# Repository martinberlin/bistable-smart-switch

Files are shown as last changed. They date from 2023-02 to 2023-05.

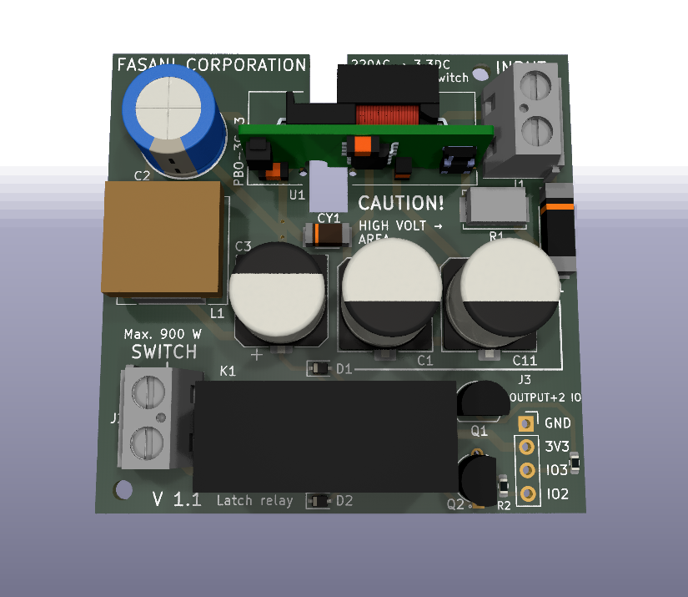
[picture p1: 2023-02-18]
Hardware/220AC-mini-C3-board/3D/img/3d-top.png

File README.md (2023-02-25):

**IMPORTANT:** This repository contains components added as github submodules. Please clone it using

    git clone --recurse-submodules https://github.com/martinberlin/bistable-smart-switch.git
        or if you already cloned it without them just run additionally:
    git submodule update --init --recursive

# Bistable-smart-switch

This is a project that started with the idea to use small, and inexpensive, SPI epapers with touch. The ones that I've found available and met that criteria are produced by Good-Display in Dalian.
The idea is very simple: 

> Use this bistable displays, or any others with very low consumption, to design a Switch that can replace a standard European one.

I know is a lot of technology to turn on the light and at some point I though that no-one will buy a digital switch for a spaceship.

**But it turns out that it got some attention since there are some interesting points that drive this:**

- **ESP32-C3** is also an unexpensive, single Core, RISC-V Espressif MCU with 4 MB flash and the usual BLE/ WiFi combination
- **Having touch and UX with a bistable display**, using our own component CalEPD and our own touch fork, gives us the freedom to be Code-light and make versatile examples that everyone can extend and collaborate
- **ESP-Rainmaker** is a possibility that we already tested, so you can also turn ON/OFF the light with their application
- **There are no similar smart switches** that come with full schematics, PCB's and example Firmware. If there are please tell us where since I'm interested to see what others are doing (We know already jung.de the zamel.com polish brand and more) But none of them offers a hackeable switch.

All that we have already but it was around different repositories, where you had to configure CMakeFiles to point it to the right example and more...
The goal of this repo is to put all this Switch ideas and code demos in a single place, make a WiKi with configuration tutorials and documentation. Just make it easy for the user to get started and build his first working Firmware in 10 minutes.

With the current hardware and demo examples what you can do is straight-forward. You can design a switch, since we provide a very basic example, and detect touch X & Y events. Based on that you can send signals to the Latch relay PCB and move the switch to the ON or OFF position.
But is your switch. You could draw something using GFX over. Soon we will add examples to load images from WiFi and other cool things. And Latch relay is low consumption, you just move it with a 50 ms signal, then it stays in that position.
It has no way to tell in what position is from outside but we know it since by default the ESP32 C3 moves it to OFF as the Firmware starts.

## The hardware

It consists in two PCBs and the display using C3 as Microcontroller:

1. **ESP32-C3 controller with touch**
2. **220AC to 3.3DC adapter with a Latch relay switch**. 54x54 mm so it fits in the small black box inside the wall Can be also a solid-state relay or you can design your own
3. **The 2.7" display** with touch [GDEY027T91-T](https://github.com/martinberlin/cale-idf/wiki/Good-Display-gdey027T91)

C3 controller

3D-mains-power

2.7 touch FocalTech

This is the touch panel that comes already on top of the display. Check the [GOODISPLAY product page](https://www.good-display.com/product/2.7-inch-touch-screen,-for-2.7-inch-e-paper-display-259.html) for specifications and datasheet.

More pictures and documentation will be added in the WiKi section, that is better to keep things organized and inter-linked than a single readme page.

## IO configuration

We will keep mostly the same "proven to work" IOs along the PCB versions but it might be that routing is simpler using different pins for SPI. To keep it organized the default sdkconfig will point to PCB latest release (In this case 1.1) and we will keep track of the right IO config for different versions in the [sdk-config-board](sdk-config-board) directory.

As an example if you have a 1.0 PCB, you can simply cp that sdkconfig to your project one doing this from the project root folder:

    $ cp sdk-config-board/1.0/sdkconfig .

Alternatively you can configure this the usual way with ESP-IDF using menuconfig:

    idf.py menuconfig

    SPI configuration is located in: **Component config → SPI epaper configuration**

    I2C and RTC configuration: **Root → RTC & I2C Configuration**

    WiFi connection for RTC sync: **Root → Example Connection Configuration**

## The code examples

1. [Getting started](main/switch/getting-started) a simple ON-OFF basic switch. No configuration required.

More will soon land here. For the moment they are in mother repository cale-idf that is an incredible mess where I develop the components and is full of examples, that I promised myself to reorganize, and I will probably never do.
Just be patient, life takes it's times, just like the hardware design part and examples.

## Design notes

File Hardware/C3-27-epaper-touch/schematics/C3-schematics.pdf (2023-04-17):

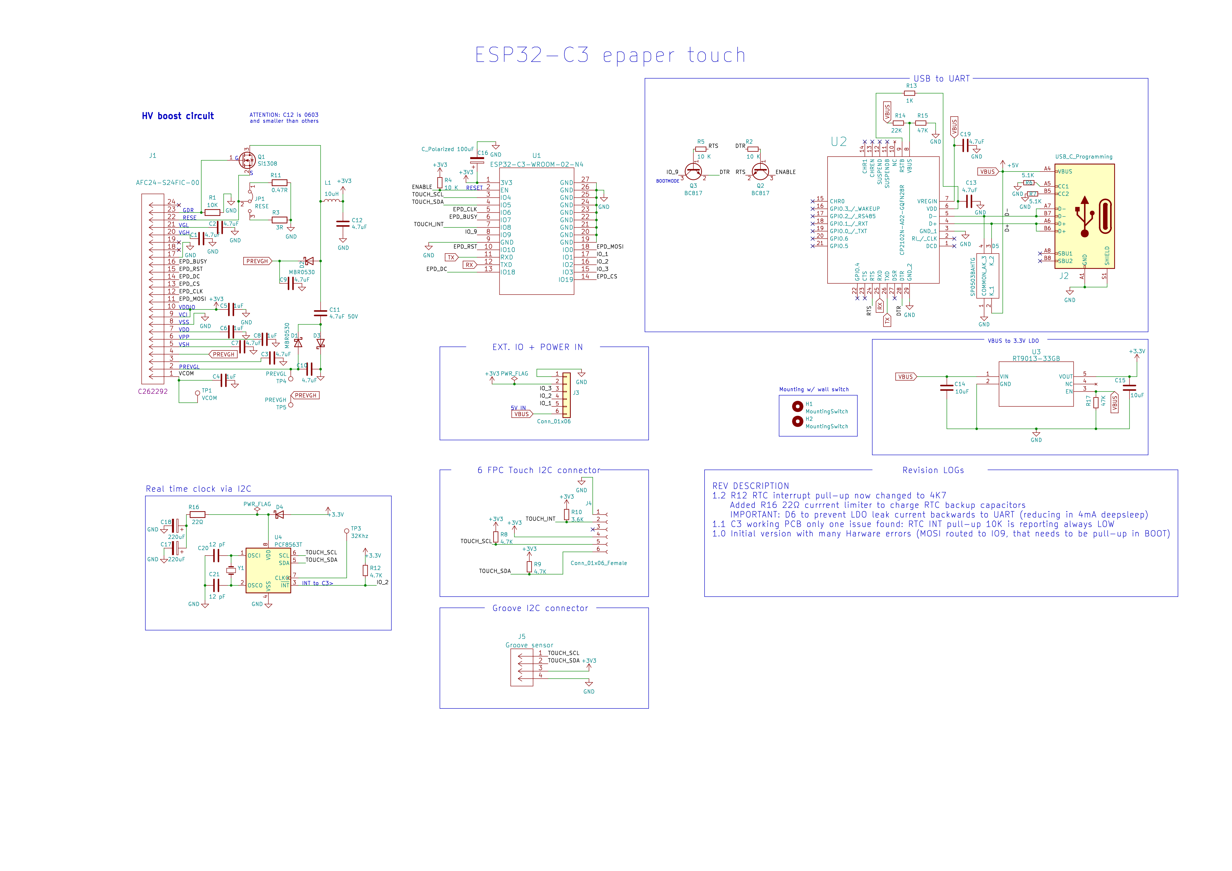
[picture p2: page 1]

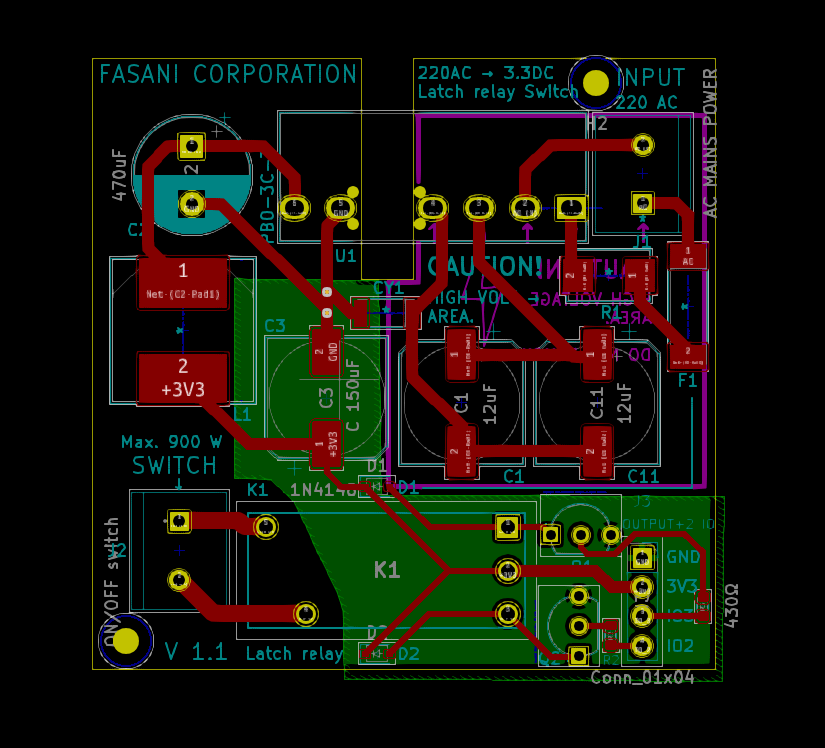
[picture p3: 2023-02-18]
Hardware/220AC-mini-C3-board/3D/img/PCB-top-view.png

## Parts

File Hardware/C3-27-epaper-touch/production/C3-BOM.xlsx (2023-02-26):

Designator | Footprint | Comment | JLPCB Part#
D4 | D_SOD-323 | 1N5819WS | C191023
C2,C7,C9,C10,C19,C1,C3 | C_0805_2012Metric_Pad1.18x1.45mm_HandSolder | 4.7uF | C1779
Q2,Q3 | SOT-23 | BC817 | C146798
C8,C4,C6,C5 | C_0805_2012Metric_Pad1.18x1.45mm_HandSolder | 1uF | C28323
J2 | USB_C_Receptacle_HRO_TYPE-C-31-M-12 | USB_C_Programming | C165948
U3 | SOT-23 | MCP1700-3302E_SOT23 | C39051
R13 | R_0603_1608Metric | 1K | C21190
C11 | C_0805_2012Metric_Pad1.18x1.45mm_HandSolder | 4.7uF 50V | C1779
R11 | R_0603_1608Metric | 0.47R | C103895
C17,C18 | CP_EIA-3528-21_Kemet-B | 220uF | C122252
R3 | R_0603_1608Metric | 3R | C25237
D5 | SP0503BAHTG | SP0503BAHTG | C3040626
U4 | SOIC-8_3.9x4.9mm_P1.27mm | PCF8563T | C7440
Y1 | Q13FC1350000400-Crystal | Crystal_Small | C32346
R2,R5,R12,R4 | R_0603_1608Metric | 10 K | C25804
C21,C20 | C_0603_1608Metric | 12 pF | C38523
JP1 | switch-MK-12C02-G020 | RESE | C2911519
C14,C15 | C_0805_2012Metric | 10uF | C15850
J1 | AFC24-S24FIC-00 | AFC24-S24FIC-00 | C262292
R7,R6 | R_0603_1608Metric | 5.1K | C23186
D1,D3,D2 | D_SOD-123 | MBR0530 | C77336
C13 | C_0805_2012Metric | 4.7uF | C1779
R10 | R_0603_1608Metric | 3.6K | C22980
C16 | CP_EIA-3528-21_Kemet-B | C_Polarized 100uF | C129289
R1 | R_0603_1608Metric | 10K | C25804
J4 | FH34SRJ-6S-0.5SH50-Hirose | Conn_01x06_Female | C224194
R9,R8 | R_0603_1608Metric | 4.7K | C23162
U2 | CP2102-QFN50P500X500X80-29N-D | CP2102N-A02-GQFN28R | C964632
R15 | R_0603_1608Metric | 47.5K | C137715
Q1 | SOT-323_SC-70 | Si1308 | C469327
C12 | C_0603_1608Metric | 4.7uF | C19666
L1 | SWPA4030S1R0NT | 10uH | C38117
R14 | R_0603_1608Metric | 22K | C31850
U1 | ESP32-C3 |  | C2934560

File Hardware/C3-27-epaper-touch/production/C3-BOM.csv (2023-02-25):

Id | Designator | Package | Quantity | Designation | Supplier and ref
1 | D4 | D_SOD-323 | 1 | 1N5819WS
2 | C2,C7,C9,C10,C19,C1,C3 | C_0805_2012Metric_Pad1.18x1.45mm_HandSolder | 7 | 4.7uF
3 | TP3 | TestPoint_Pad_D1.5mm | 1 | 32Khz
4 | U1 | ESP32-C3-WROOM-02-N4 | 1 | ESP32-C3-WROOM-02-N4
5 | Q2,Q3 | SOT-23 | 2 | BC817
6 | C8,C4,C6,C5 | C_0805_2012Metric_Pad1.18x1.45mm_HandSolder | 4 | 1uF
7 | J2 | USB_C_Receptacle_HRO_TYPE-C-31-M-12 | 1 | USB_C_Programming
8 | U3 | SOT-23 | 1 | MCP1700-3302E_SOT23
9 | R13 | R_0603_1608Metric | 1 | 1K
10 | C11 | C_0805_2012Metric_Pad1.18x1.45mm_HandSolder | 1 | 4.7uF 50V
11 | R11 | R_0603_1608Metric | 1 | 0.47R
12 | C17,C18 | CP_EIA-3528-21_Kemet-B | 2 | 220uF
13 | R3 | R_0603_1608Metric | 1 | 3R
14 | D5 | SP0503BAHTG | 1 | SP0503BAHTG
15 | U4 | SOIC-8_3.9x4.9mm_P1.27mm | 1 | PCF8563T
16 | Y1 | Q13FC1350000400-Crystal | 1 | Crystal_Small
17 | R2,R5,R12,R4 | R_0603_1608Metric | 4 | 10 K
18 | C21,C20 | C_0603_1608Metric | 2 | 12 pF
19 | JP1 | switch-MK-12C02-G020 | 1 | RESE
20 | C14,C15 | C_0805_2012Metric | 2 | 10uF
21 | J1 | AFC24-S24FIC-00 | 1 | AFC24-S24FIC-00
22 | R7,R6 | R_0603_1608Metric | 2 | 5.1K
23 | D1,D3,D2 | D_SOD-123 | 3 | MBR0530
24 | C13 | C_0805_2012Metric | 1 | 100nF
25 | R10 | R_0603_1608Metric | 1 | 3.6K
26 | C16 | CP_EIA-3528-21_Kemet-B | 1 | C_Polarized 100uF
27 | R1 | R_0603_1608Metric | 1 | 10K
28 | J4 | FH34SRJ-6S-0.5SH50-Hirose | 1 | Conn_01x06_Female
29 | R9,R8 | R_0603_1608Metric | 2 | 4.7K
30 | U2 | CP2102-QFN50P500X500X80-29N-D | 1 | CP2102N-A02-GQFN28R
31 | R15 | R_0402_1005Metric | 1 | 47K
32 | J5 | MOLEX-I2C-532530470 | 1 | Groove sensor
33 | Q1 | SOT-323_SC-70 | 1 | Si1308
34 | C12 | C_0603_1608Metric | 1 | 4.7uF
35 | L1 | SWPA4030S1R0NT | 1 | 10uH
36 | R14 | R_0201_0603Metric | 1 | 22K

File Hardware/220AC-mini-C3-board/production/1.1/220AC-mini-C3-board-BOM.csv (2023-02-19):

Id | Designator | Package | Quantity | Designation | Supplier and ref
1 | R1 | SMW212RJT | 1 | R
2 | Q1,Q2 | BC547B | 2 | Q_NPN_CBE
3 | R2,R3 | R_0603_1608Metric | 2 | 430Ω
4 | K1 | FH44L-1AT-L2-DC3V | 1 | HF163-F
5 | C11 | CP_Elec_10x14.3 | 1 | 12uF
6 | D2,D1 | D_SOD-323 | 2 | 1N4148
7 | CY1 | CC1808KKX7RCBB102 | 1 | 1nF
8 | U1 | PBO-3C-3 | 1 | PBO-3C-3
9 | J2 | Conn_C8269 | 1 | ON/OFF switch
10 | J1 | Conn_C8269 | 1 | AC MAINS POWER
11 | C2 | CP_Radial_D10.0mm_P5.00mm | 1 | 470uF
12 | F1 | 0443001.DR | 1 | Fuse
13 | L1 | IND_BRL3225T4R7M | 1 | L
14 | C3 | CP_Elec_10x10 | 1 | C 150uF
15 | J3 | PinSocket_1x04_P2.54mm_Vertical | 1 | Conn_01x04

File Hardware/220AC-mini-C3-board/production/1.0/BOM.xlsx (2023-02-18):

Designator | Footprint | Comment | JLPCB Part#
J1 | 1729128-screw-terminal | AC MAINS POWER | C474894
R1 | SMW212RJT | R | C2073396
C1,C11 | CP_Elec_10x14.3 | 12uF | C487569
K1 | HF163FL24HL2T | HF163-F | C140724
D2,D1 | D_SOD-323 | 1N4148 | C2128
CY1 | CC1808KKX7RCBB102 | 1nF | C527384
U1 | PBO-3C-3 | PBO-3C-3 | C5346210
Q1,Q2 | BC547B | Q_NPN_CBE | C713613
C2 | CP_Radial_D10.0mm_P5.00mm | 470uF | C106488
F1 | 0443001.DR | Fuse | C95352
J2 | 1729128-screw-terminal | ON/OFF switch | C474894
C3 | CP_Elec_10x10 | C 150uF | C72490
L1 | SMDRI127-470MT | L | C24548

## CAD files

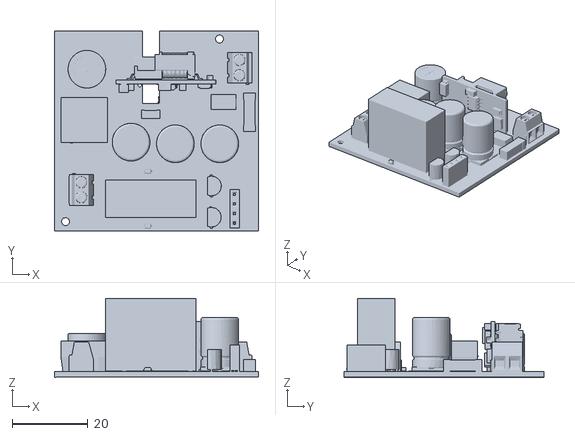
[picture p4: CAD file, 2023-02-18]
Hardware/220AC-mini-C3-board/3D/220ac-mini-c3-board.stl
54.0 x 53.0 x 20.9

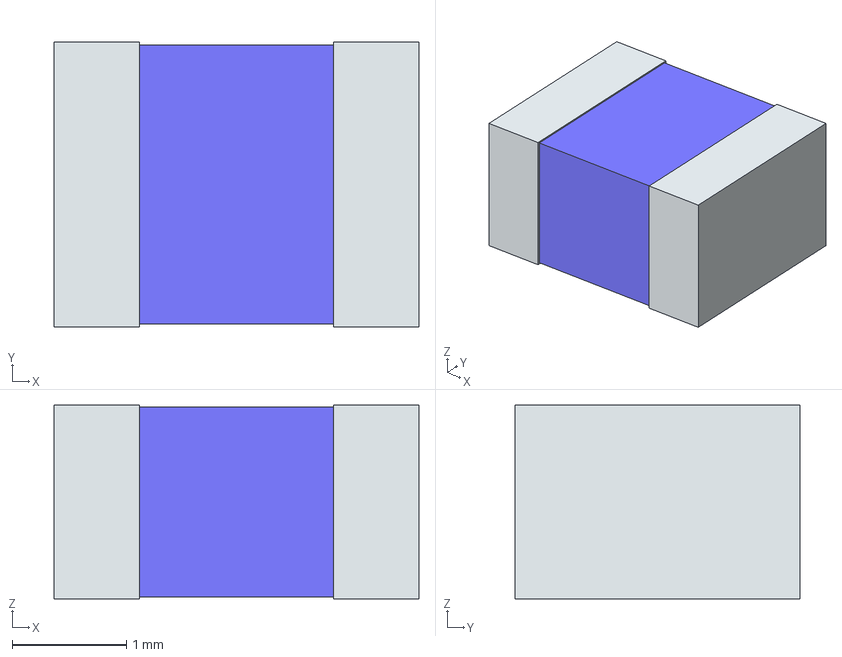
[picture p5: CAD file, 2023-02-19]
Hardware/220AC-mini-C3-board/parts/3d/BRL3225T4R7M-L1.step
3.20 x 2.50 x 1.70 mm
term1
term2

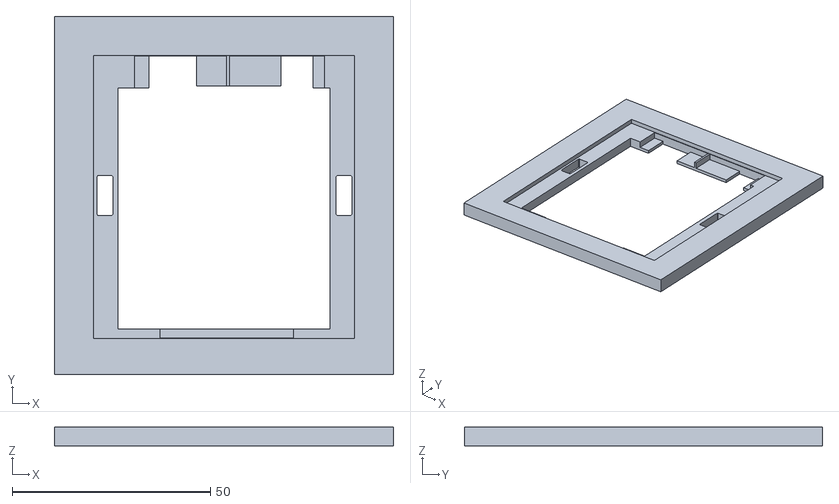
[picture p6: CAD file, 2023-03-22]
Hardware/3D/case-switch-epaper.stl
85.5 x 90.2 x 4.73

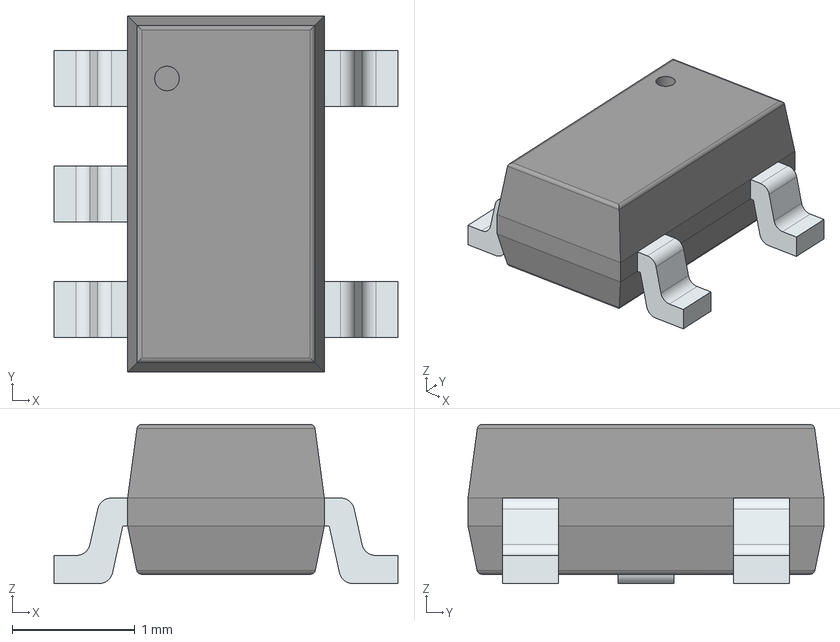
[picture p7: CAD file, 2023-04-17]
Hardware/C3-27-epaper-touch/parts/3d/RT9013-33GB.step
2.79 x 2.90 x 1.29 mm
PinsArrayL
PinsArrayR

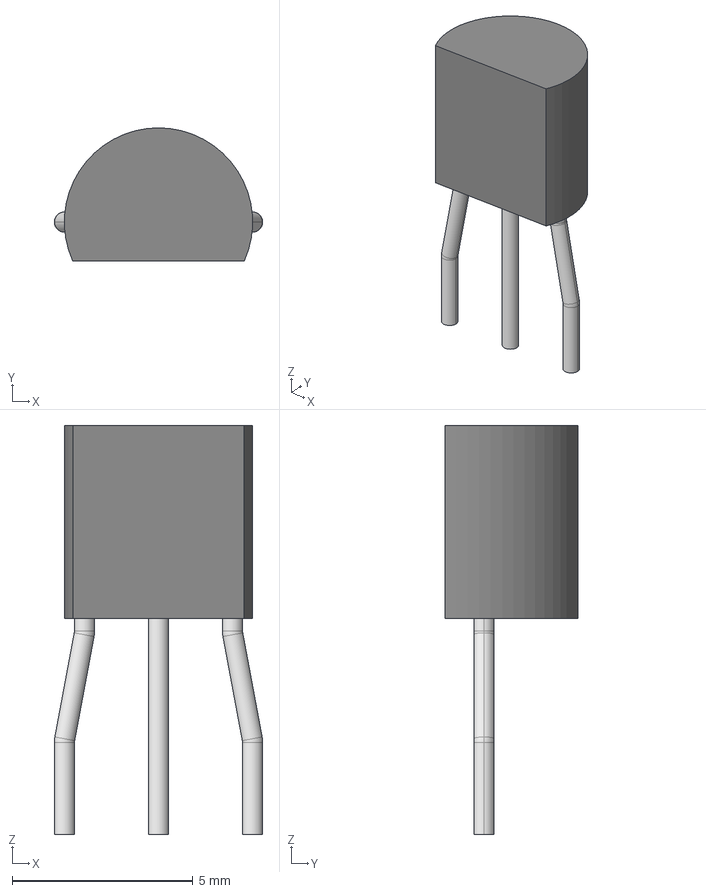
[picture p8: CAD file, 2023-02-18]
Hardware/220AC-mini-C3-board/parts/3d/TO-92-3L_5P33X5P2_ONS.step
5.76 x 3.68 x 11.3 mm

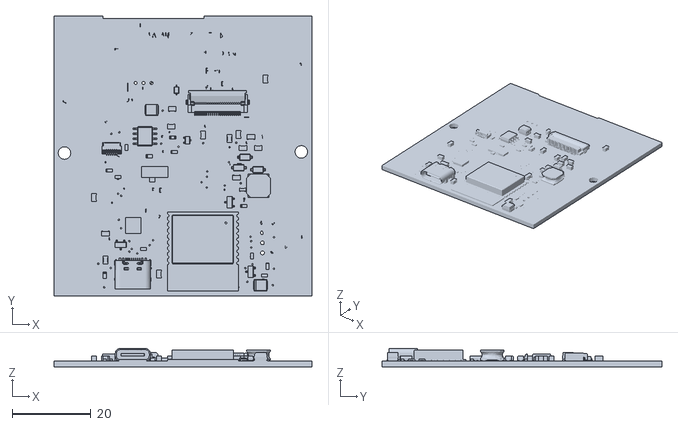
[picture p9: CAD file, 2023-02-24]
Hardware/C3-27-epaper-touch/3D/C3-27-epaper-touch-3D.stl
65.4 x 71.0 x 4.84

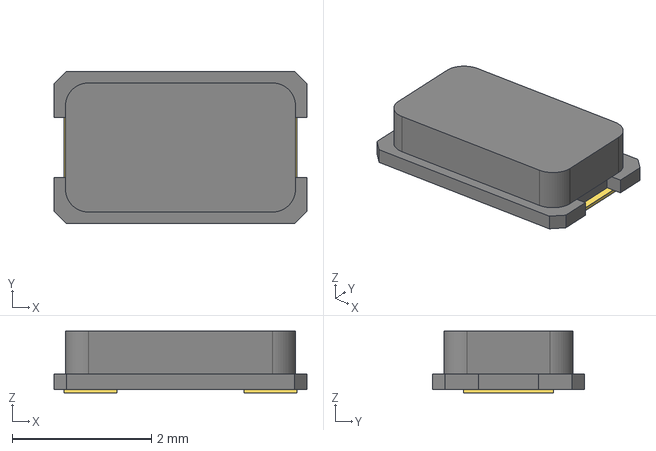
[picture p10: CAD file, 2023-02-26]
Hardware/C3-27-epaper-touch/parts/3d/XTAL_FC-135_EPS.step
3.63 x 2.18 x 0.889 mm

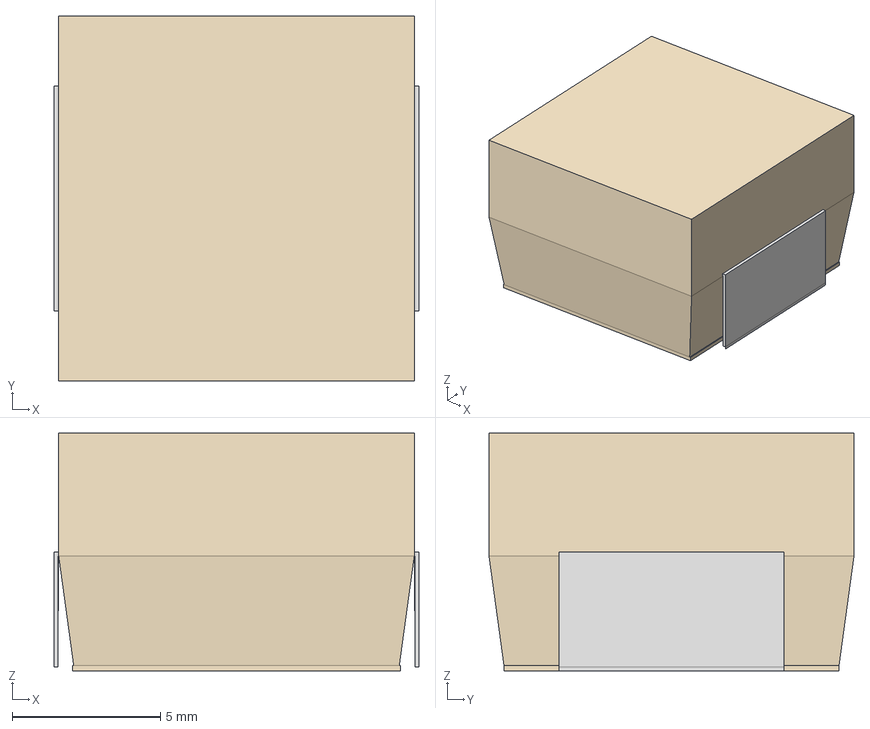
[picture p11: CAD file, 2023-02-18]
Hardware/220AC-mini-C3-board/parts/3d/IND_SMDRI_SXN.step
12.3 x 12.3 x 8.00 mm

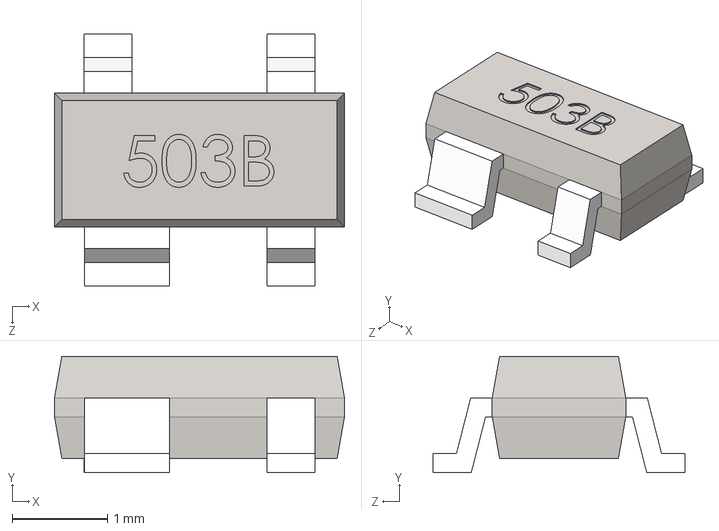
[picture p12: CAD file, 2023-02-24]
Hardware/C3-27-epaper-touch/parts/3d/SP0503BAHTG-ESD.step
3.04 x 1.22 x 2.64 mm

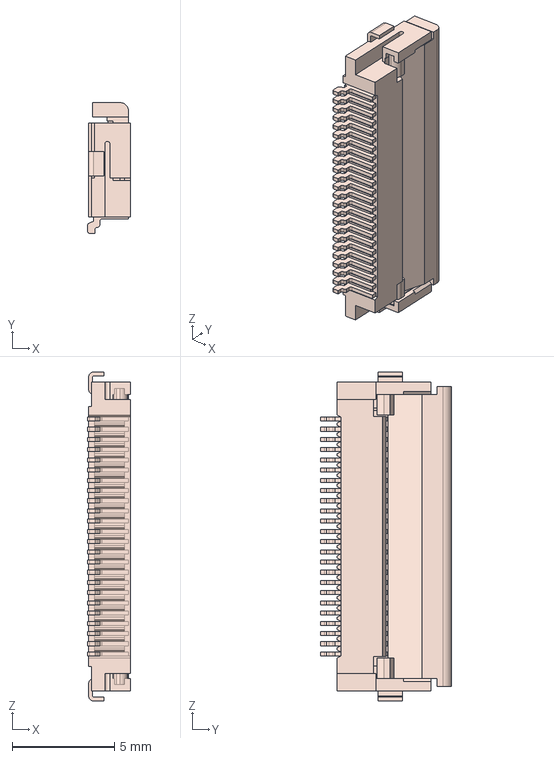
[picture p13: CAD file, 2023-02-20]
Hardware/C3-27-epaper-touch/parts/3d/FH12-24S-0.5SH_55_.step
2.10 x 6.40 x 16.1 mm

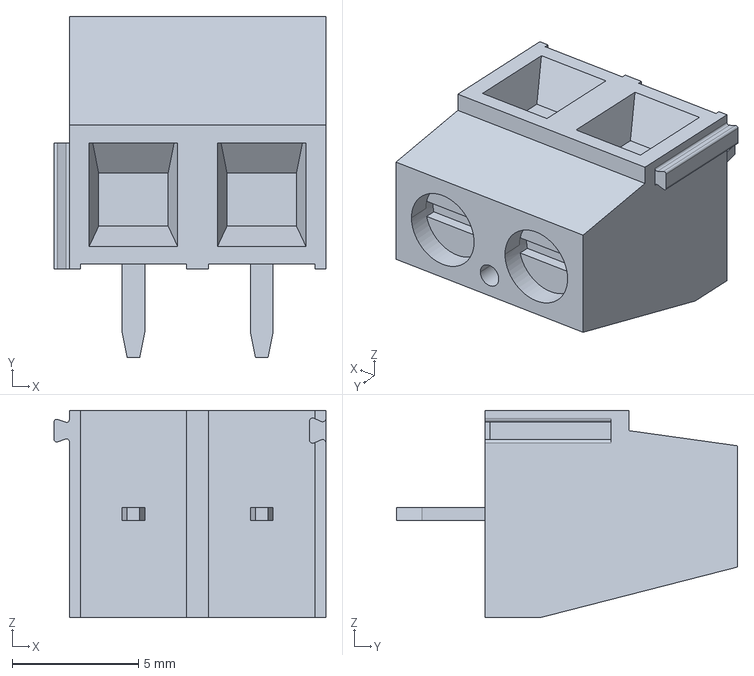
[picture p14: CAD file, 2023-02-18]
Hardware/220AC-mini-C3-board/parts/3d/C8269.step
10.8 x 13.5 x 8.20 mm

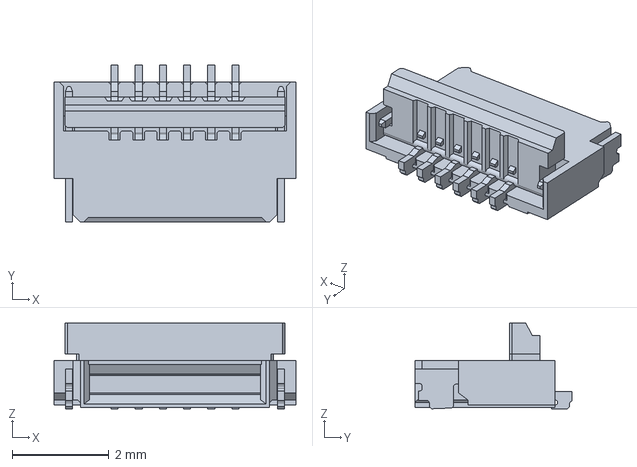
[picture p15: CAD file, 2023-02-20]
Hardware/C3-27-epaper-touch/parts/3d/FH34SRJ-6S-0.5SH50-Hirose.step
5.00 x 3.25 x 1.77 mm

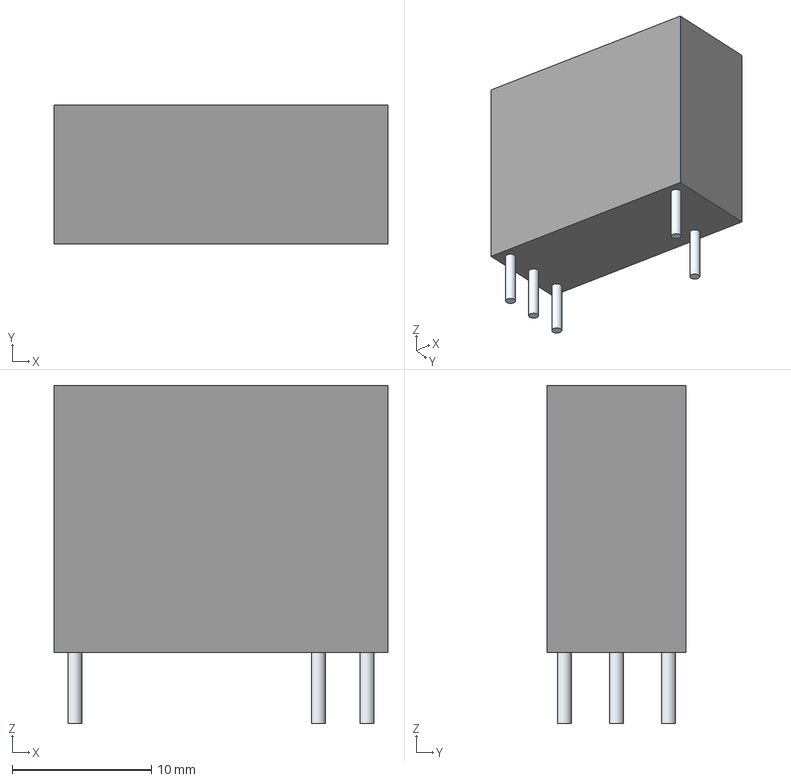
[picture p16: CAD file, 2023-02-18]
Hardware/220AC-mini-C3-board/parts/3d/HF163F-L_24-HL2T.step
24.0 x 10.0 x 24.3 mm
Leads

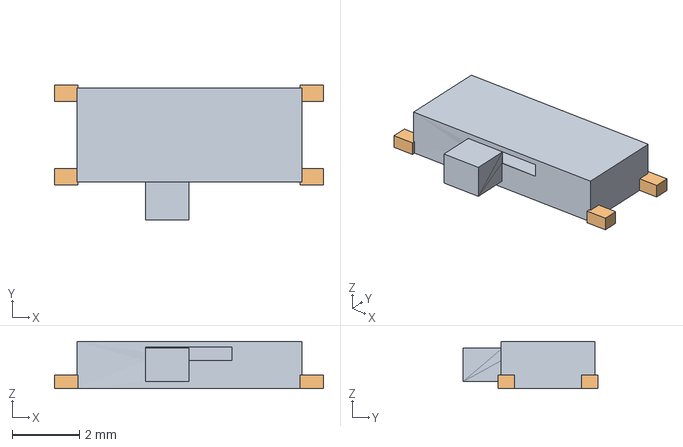
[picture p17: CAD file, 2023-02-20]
Hardware/C3-27-epaper-touch/parts/3d/MK-12C02-G015.step
8.01 x 4.03 x 1.40 mm

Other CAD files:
Hardware/C3-27-epaper-touch/3D/case-switch-epaper.stl
Hardware/S3-27-epaper-touch-pro/3D/case-switch-epaper.stl
Hardware/C3-27-epaper-touch/parts/3d/CR1220-2.step
Hardware/220AC-mini-C3-board/parts/3d/1729128-screw-terminal.stp
Hardware/3D/case-switch-epaper.blend
Hardware/C3-27-epaper-touch/parts/3d/0443Series_LTF.step
Hardware/C3-27-epaper-touch/parts/3d/AP22802AW5-7.step
Hardware/C3-27-epaper-touch/parts/3d/CP2102N-A02-GQFN28R.step
Hardware/C3-27-epaper-touch/parts/3d/ESP32-C3-WROOM-02-H4.step
Hardware/C3-27-epaper-touch/parts/3d/HRO_TYPE-C-31-M-12.step
Hardware/C3-27-epaper-touch/parts/3d/IND_0S282MT_SNL.step
Hardware/C3-27-epaper-touch/parts/3d/L-40xx.STEP
Hardware/C3-27-epaper-touch/parts/3d/c-5-1676966-1-ba-3d.stp

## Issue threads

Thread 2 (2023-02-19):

Kickstart TODOs

martinberlin, 2023-02-19:
- [x] Add ESP-Rainmaker example(s)
- [x] Start WiKi documenting those examples and making a getting started section
- [x] Move [C3-controller](https://github.com/martinberlin/H-spi-adapters) with touch PCB to this repo Hardware section

Update about this point: We will move C3 PCB when the new revision is tested. For now we copied the C3 PCB here but making a PRO version with a more powerful MCU:
ESP32-S3-WROOM-1-N8R2  (with 2MB RAM and 8MB flash) albeit more expensive at 3.9 USD this will be a more powerful option for those who want to research adding more complex Firmware or using LVGL to draw UX.

The WiKi will start soon when we have the first users of the repository.

Closed 2023-02-27.

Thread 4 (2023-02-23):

Hardware PCB improvements

martinberlin, 2023-02-23:
Let’s make a list of things that can be made better:

- [ ] Move C3 design here once it’s validated
- [ ] Add ESD protection diodes to USB
- [ ] Research abou how to add optocoupler to check that light is really consuming in main power PCB

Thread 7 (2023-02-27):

Rainmaker integration

martinberlin, 2023-02-27:
Add this device to be paired to the ESP-Rainmaker phone app

- [ ] Add 2 input forms: Device watts, Price per kilowatt
- [ ] Save the updated values in NVS

But this is not only meant to be WiFi driven for the people that do not want that. Also offer to add this stored in the Firmware without being associated to Rainmaker.

martinberlin, 2023-02-28:
@goran-mahovlic this is starting to take shape for when the S3 model is sent to fabrication.
To test it you should add any DS3231 cheap module in the same I2C than touch.

The round PCB is also done but that will need to wait until mid or end March, so there is time to review it. First prio for me would be to check that CP2102N cheaper model QFN28 works as expected before finishing S3 prototype

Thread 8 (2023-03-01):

Kw measurements and cost calculation

martinberlin, 2023-03-01:
In this issue we can discuss, plan, and mention it in the commits where the formula is modified.

Main task will be to build a simple CPP main program that counts how much seconds the switch is on and based on this inputs:

```C
#define DEVICE_CONSUMPTION 100
double  DEVICE_KW_HOUR_COST = 0.4;
```

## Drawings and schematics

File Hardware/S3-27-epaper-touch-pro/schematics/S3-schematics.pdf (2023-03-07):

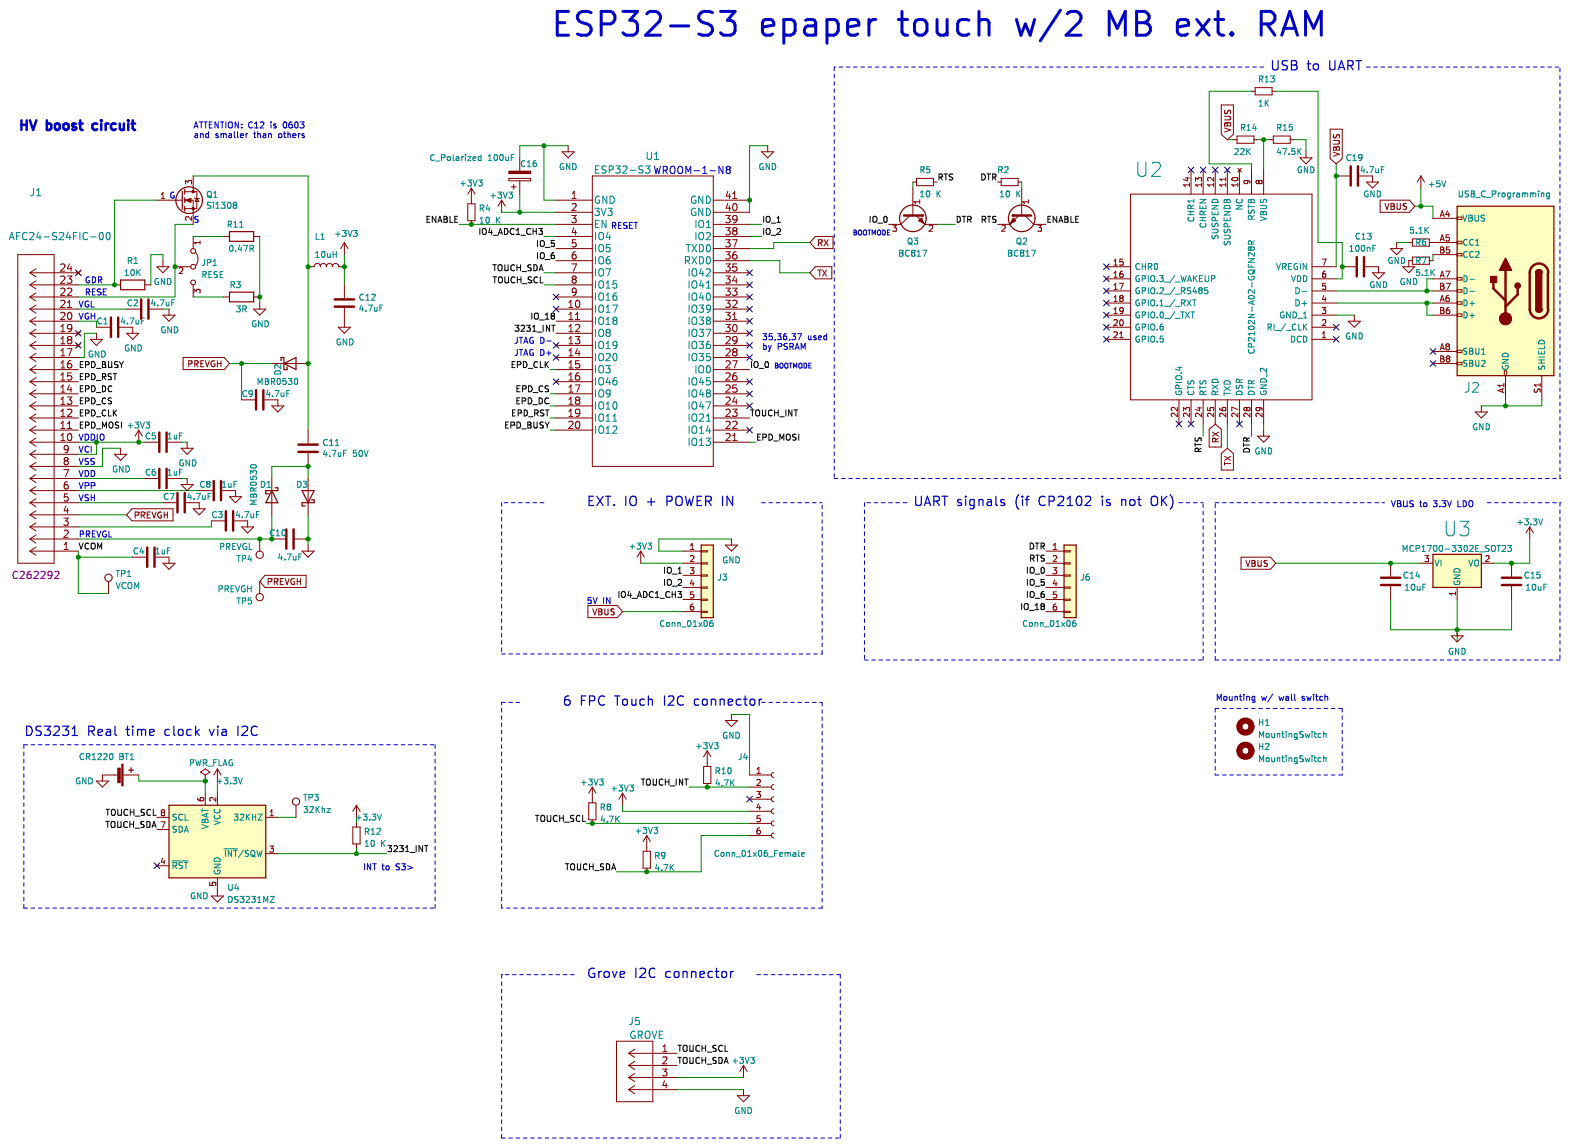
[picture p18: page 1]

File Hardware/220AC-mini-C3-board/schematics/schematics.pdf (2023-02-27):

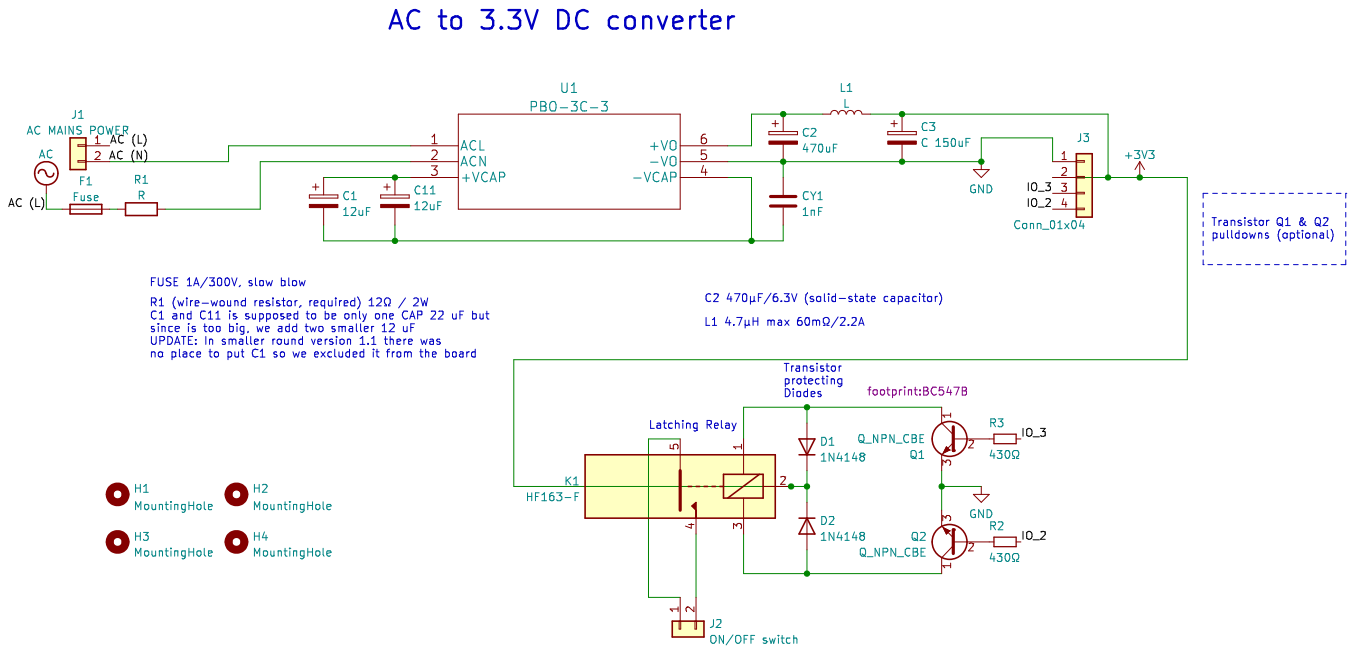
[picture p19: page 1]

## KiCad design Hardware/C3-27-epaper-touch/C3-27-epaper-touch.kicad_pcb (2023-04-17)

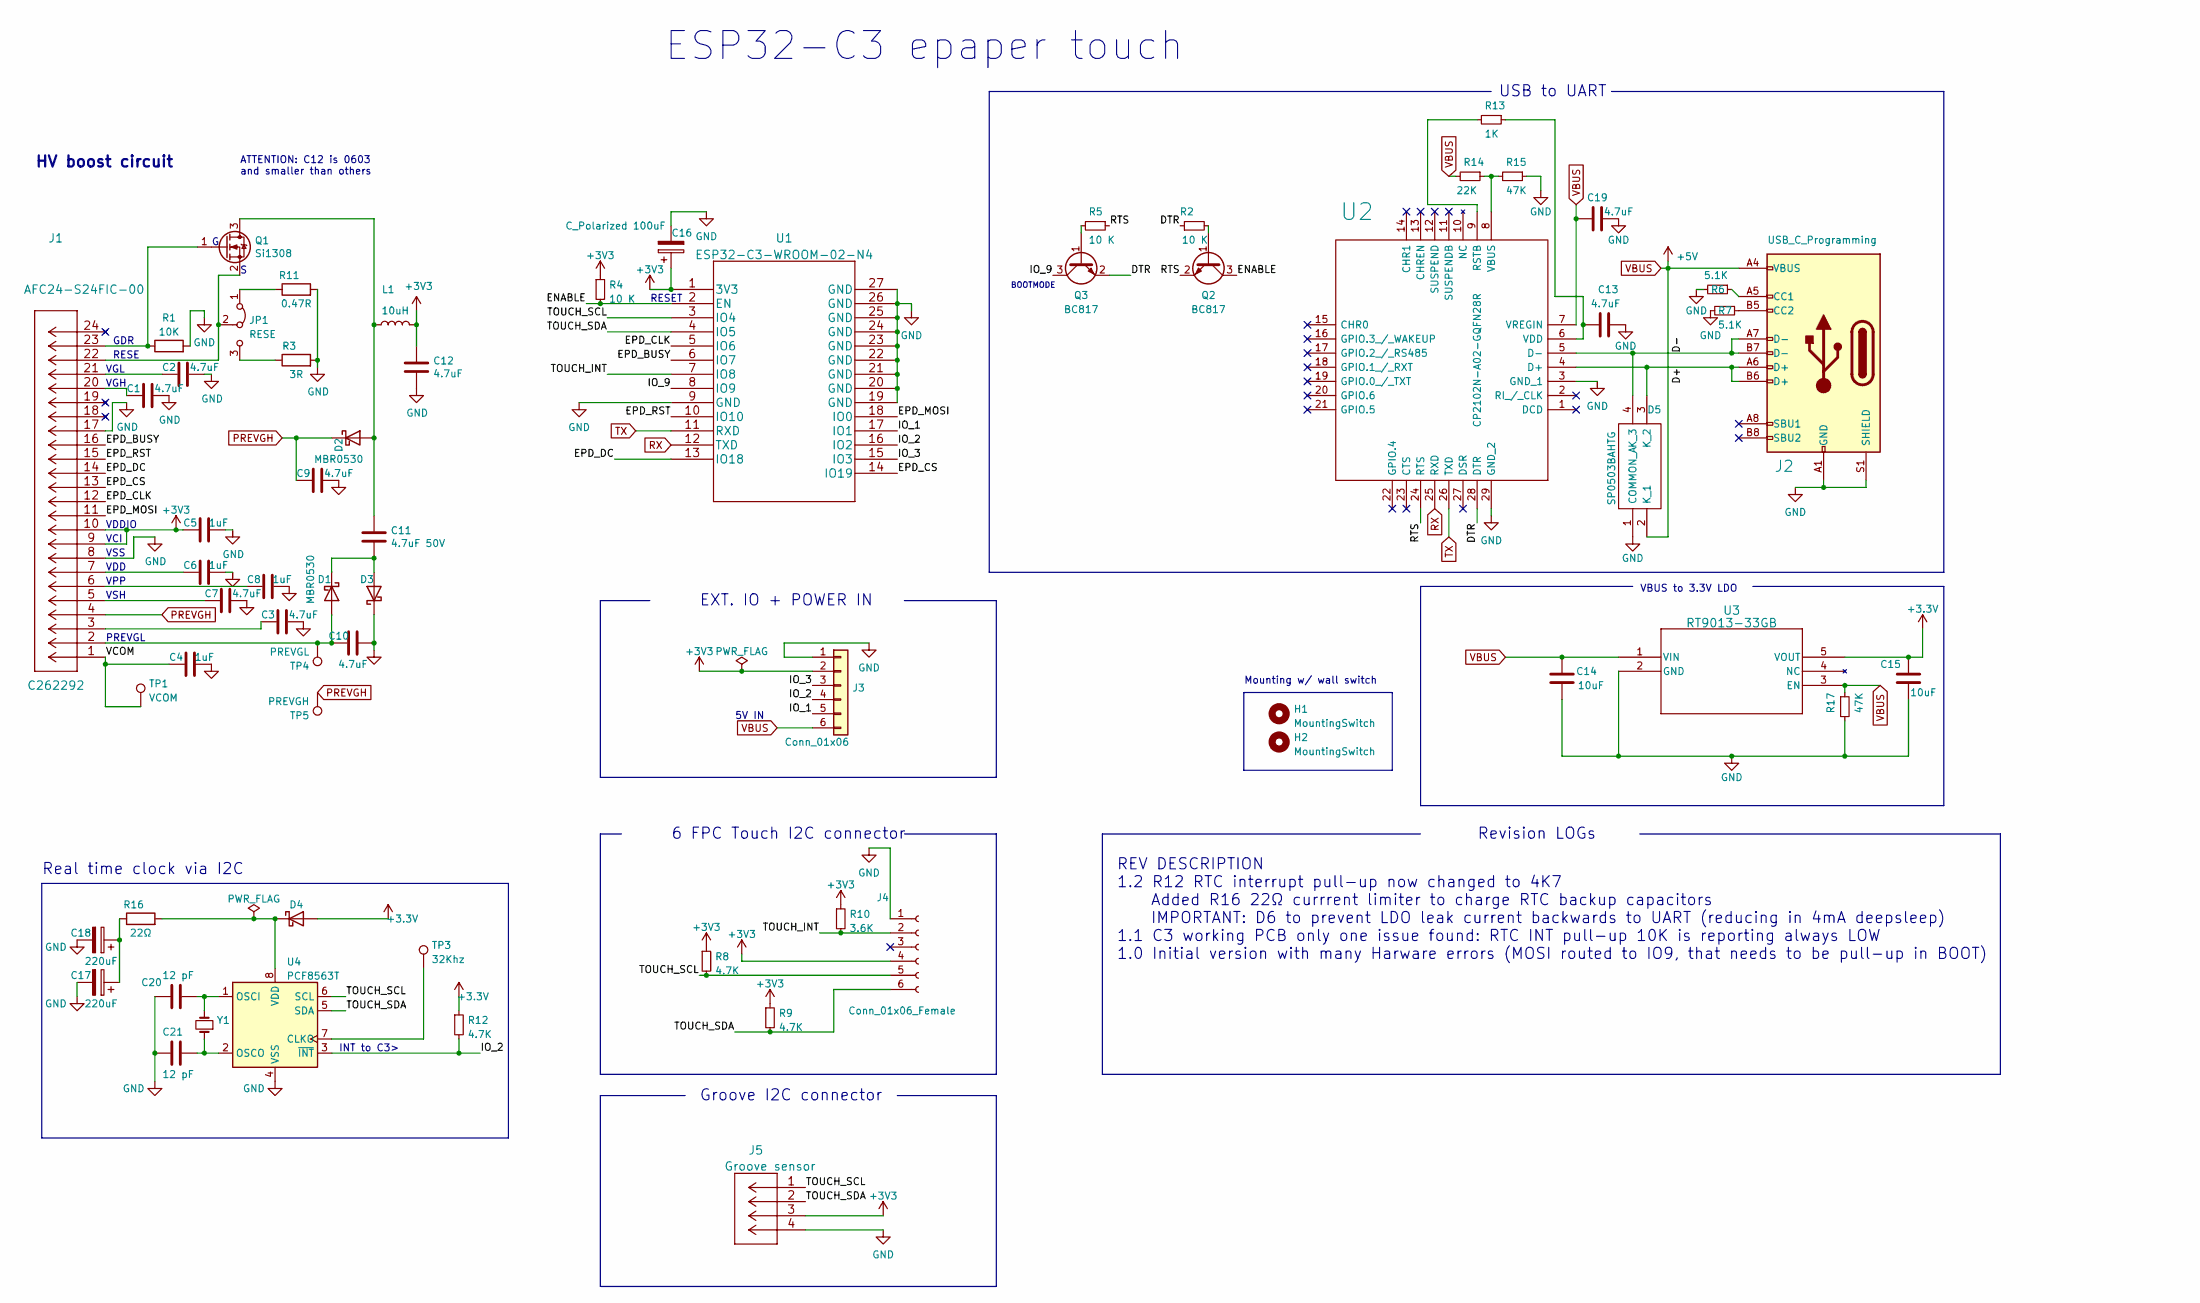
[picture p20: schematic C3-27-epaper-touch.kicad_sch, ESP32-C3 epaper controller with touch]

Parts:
C1, C2, C3, C7, C9, C10, C19: 4.7uF; C_0805_2012Metric_Pad1.18x1.45mm_HandSolder; LCSC C1779
C4, C5, C6, C8: 1uF; C_0805_2012Metric_Pad1.18x1.45mm_HandSolder; LCSC C28323
C11: 4.7uF 50V; C_0805_2012Metric_Pad1.18x1.45mm_HandSolder; LCSC C1779
C12: 4.7uF; C_0603_1608Metric; LCSC C19666
C13: 4.7uF; C_0805_2012Metric; LCSC C1779
C14, C15: 10uF; C_0805_2012Metric; LCSC C15850
C16: C_Polarized 100uF; CP_EIA-3528-21_Kemet-B; LCSC C129289
C17, C18: 220uF; CP_EIA-3528-21_Kemet-B; LCSC C122252
C20, C21: 12 pF; C_0603_1608Metric; LCSC C38523
D1, D2, D3: MBR0530; D_SOD-123; LCSC C77336
D4: 1N5819WS; D_SOD-323; LCSC C191023
D5: SP0503BAHTG; Manufacturer_Part_Number SP0503BAHTG; LCSC C3040626
H1, H2: MountingSwitch; MountingHole_3.2mm_M3
J1: AFC24-S24FIC-00
J2: USB_C_Programming; USB_C_Receptacle_HRO_TYPE-C-31-M-12; LCSC C165948
J3: Conn_01x06; PinSocket_1x06_P2.54mm_Vertical
J4: Conn_01x06_Female; FH34SRJ-6S-0.5SH50-Hirose; LCSC C224194
J5: Groove sensor; MOLEX-I2C-Groove
JP1: RESE; switch-MK-12C02-G020; LCSC C2911519
L1: 10uH; SWPA4030S1R0NT; LCSC C38117
Q1: Si1308; SOT-323_SC-70; LCSC C469327
Q2, Q3: BC817; SOT-23; LCSC C146798
R1: 10K; R_0603_1608Metric; LCSC C25804
R2, R4, R5: 10 K; R_0603_1608Metric; LCSC C25804
R3: 3R; R_0603_1608Metric; LCSC C25237
R6, R7: 5.1K; R_0603_1608Metric; LCSC C23186
R8, R9, R12: 4.7K; R_0603_1608Metric; LCSC C23162
R10: 3.6K; R_0603_1608Metric; LCSC C22980
R11: 0.47R; R_0603_1608Metric; LCSC C103895
R13: 1K; R_0603_1608Metric; LCSC C21190
R14: 22K; R_0603_1608Metric; LCSC C31850
R15, R17: 47K; R_0603_1608Metric; LCSC C137715
R16: 22Ω; R_0603_1608Metric; LCSC C177566
TP1: VCOM; TestPoint_Pad_D1.5mm
TP3: 32Khz; TestPoint_Pad_D1.5mm
TP4: PREVGL; TestPoint_Pad_D1.5mm
TP5: PREVGH; TestPoint_Pad_D1.5mm
U1: ESP32-C3-WROOM-02-N4; LCSC C2934560
U2: CP2102N-A02-GQFN28R; CP2102-QFN50P500X500X80-29N-D; Manufacturer_Part_Number CP2102N-A02-GQFN28R; Mouser Part Number 634-CP2102NA02QFN28R
U3: RT9013-33GB
U4: PCF8563T; SOIC-8_3.9x4.9mm_P1.27mm; LCSC C7440
Y1: Crystal_Small; Q13FC1350000400-Crystal; LCSC C32346

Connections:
/D+: D5.3 (K_2), J2.A6 (D+), J2.B6 (D+), U2.4 (D+)
/D-: D5.4 (K_3), J2.A7 (D-), J2.B7 (D-), U2.5 (D-)
/DTR: Q3.2 (E), R2.1, U2.28 (DTR)
/ENABLE: Q2.3 (C), R4.2, U1.2 (EN)
/EPD_BUSY: J1.16, U1.6 (IO7)
/EPD_CLK: J1.12, U1.5 (IO6)
/EPD_CS: J1.13, U1.14 (IO19)
/EPD_DC: J1.14, U1.13 (IO18)
/EPD_MOSI: J1.11, U1.18 (IO0)
/EPD_RST: J1.15, U1.10 (IO10)
/IO_1: J3.5, U1.17 (IO1)
/IO_2: J3.4, R12.2, U1.16 (IO2), U4.3 (~INT)
/IO_3: J3.3, U1.15 (IO3)
/IO_9: Q3.3 (C), U1.8 (IO9)
/RTS: Q2.2 (E), R5.1, U2.24 (RTS)
/TOUCH_INT: J4.2, R10.2, U1.7 (IO8)
/TOUCH_SCL: J4.5, J5.1, R8.2, U1.3 (IO4), U4.6 (SCL)
/TOUCH_SDA: J4.6, J5.2, R9.2, U1.4 (IO5), U4.5 (SDA)
/VCOM: C4.2, J1.1, TP1.1
GND: C1.1, C2.1, C3.1, C4.1, C5.1, C6.1, C7.1, C8.1, C9.1, C10.1, C12.1, C13.2, C14.2, C15.2, C16.2, C17.2, C18.2, C19.1, C20.1, C21.1, D3.1 (K), D5.1 (COMMON_A), J1.8, J1.17, J2.A1 (GND), J2.A12 (GND), J2.B1 (GND), J2.B12 (GND), J2.S1 (SHIELD), J3.1, J4.1, J5.4, R1.2, R3.2, R6.2, R7.2, R11.2, R15.1, R17.2, U1.9 (GND), U1.19 (GND), U1.20 (GND), U1.21 (GND), U1.22 (GND), U1.23 (GND), U1.24 (GND), U1.25 (GND), U1.26 (GND), U1.27 (GND), U2.3 (GND_1), U2.29 (GND_2), U3.2 (GND), U4.4 (VSS)
unnamed: C1.2, J1.20
unnamed: C2.2, J1.21
unnamed: C3.2, J1.3
unnamed: C6.2, J1.7
unnamed: C7.2, J1.5
unnamed: C8.2, J1.6
unnamed: C17.1, C18.1, R16.1
unnamed: C10.2, D1.2 (A), J1.2, TP4.1
unnamed: C11.1, D1.1 (K), D3.2 (A)
unnamed: C11.2, D2.2 (A), L1.1, Q1.3 (D)
unnamed: D4.1 (K), R16.2, U4.8 (VDD)
unnamed: J2.A5 (CC1), R6.1
unnamed: J2.B5 (CC2), R7.1
unnamed: JP1.1 (A), R11.1
unnamed: JP1.3 (B), R3.1
unnamed: J1.22, JP1.2 (C), Q1.2 (S)
unnamed: J1.23, Q1.1 (G), R1.1
unnamed: Q2.1 (B), R2.2
unnamed: Q3.1 (B), R5.2
unnamed: R13.2, U2.9 (RSTB)
unnamed: R14.1, R15.2, U2.8 (VBUS)
unnamed: C13.1, R13.1, U2.6 (VDD)
unnamed: TP3.1, U4.7 (CLKO)
unnamed: C20.2, U4.1 (OSCI), Y1.2
unnamed: C21.2, U4.2 (OSCO), Y1.1
PREVGH: C9.2, D2.1 (K), J1.4, TP5.1
RX: U1.12 (TXD), U2.25 (RXD)
TX: U1.11 (RXD), U2.26 (TXD)
VBUS: C14.1, C19.2, D5.2 (K_1), J2.A4 (VBUS), J2.A9 (VBUS), J2.B4 (VBUS), J2.B9 (VBUS), J3.6, R14.2, R17.1, U2.7 (VREGIN), U3.1 (VIN), U3.3 (EN)

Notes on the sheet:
PREVGL
EXT. IO + POWER IN
RESE
VCI
VDDIO
REV DESCRIPTION 1.2 R12 RTC interrupt pull-up now changed to 4K7 Added R16 22Ω currrent limiter to charge RTC backup capacitors IMPORTANT: D6 to prevent LDO leak current backwards to UART (reducing in 4mA deepsleep) 1.1 C3 working PCB only one issue found: RTC INT pull-up 10K is reporting always LO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
Groove I2C connector
Revision LOGs
Real time clock via I2C
INT to C3>
BOOTMODE
5V IN
6 FPC Touch I2C connector
VDD
VSH
VSS
VPP
VGL
RESET
ATTENTION: C12 is 0603 and smaller than others
VGH
USB to UART
VBUS to 3.3V LDO
GDR
ESP32-C3 epaper touch
Mounting w/ wall switch
HV boost circuit

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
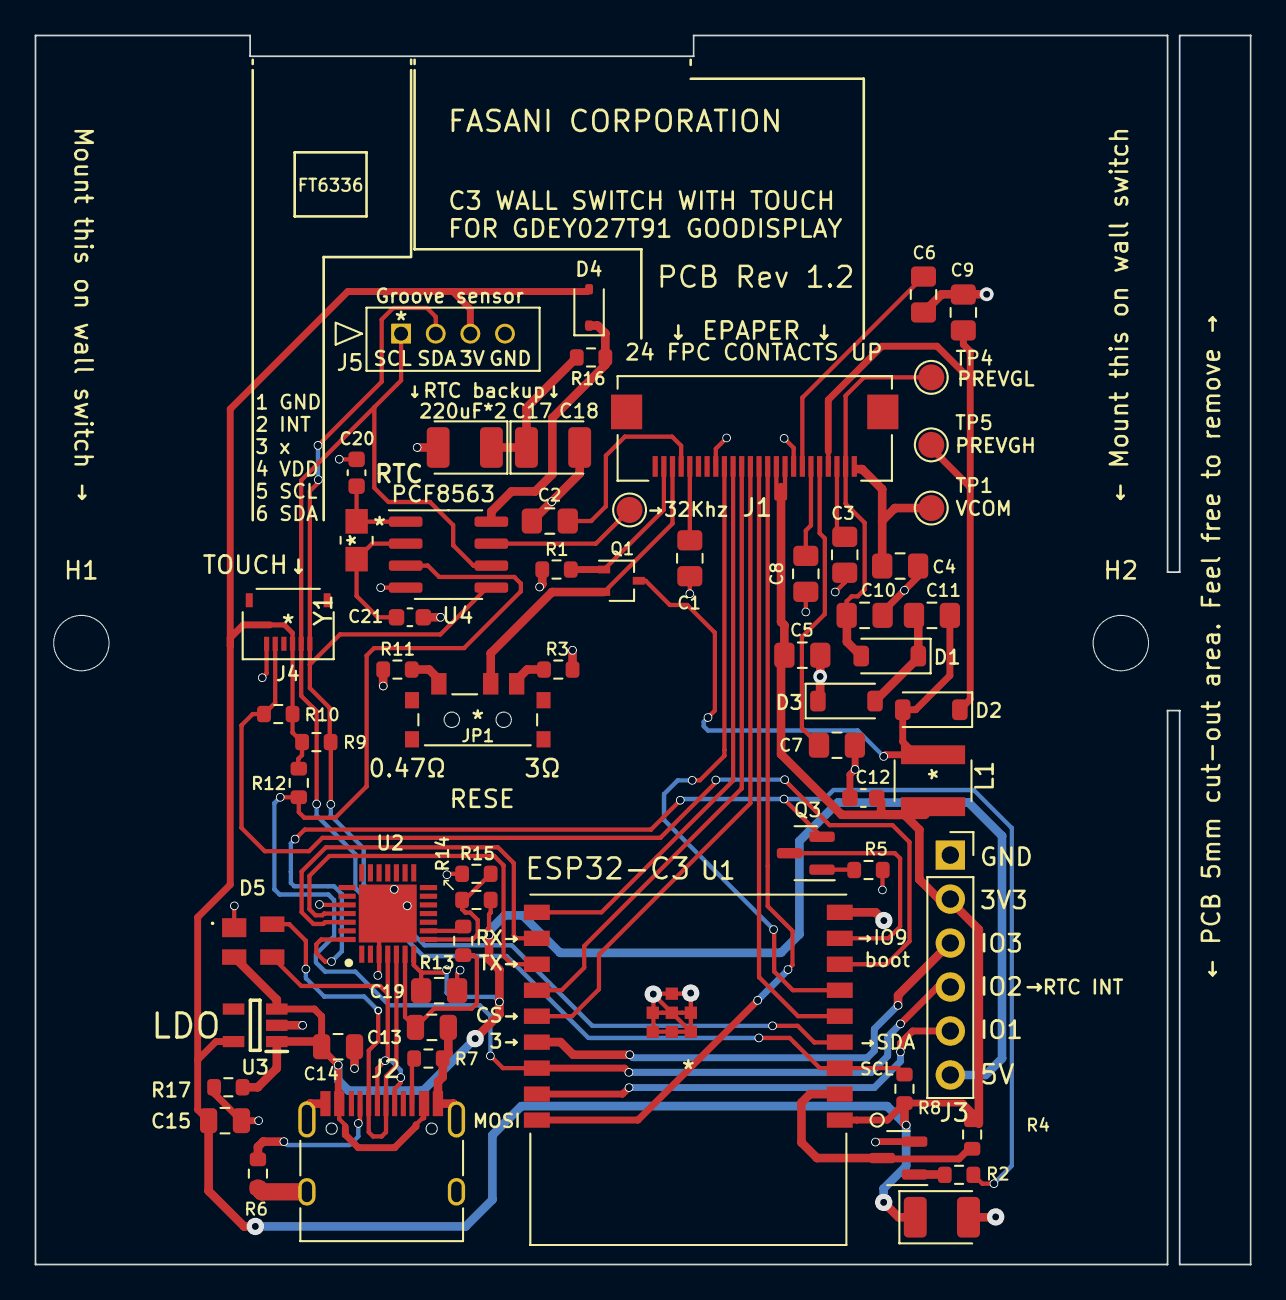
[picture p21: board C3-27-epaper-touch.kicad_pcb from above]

Board: 4 copper layers, 70.2 x 71.0 mm, 64 parts (0 on the bottom side), 50 nets.

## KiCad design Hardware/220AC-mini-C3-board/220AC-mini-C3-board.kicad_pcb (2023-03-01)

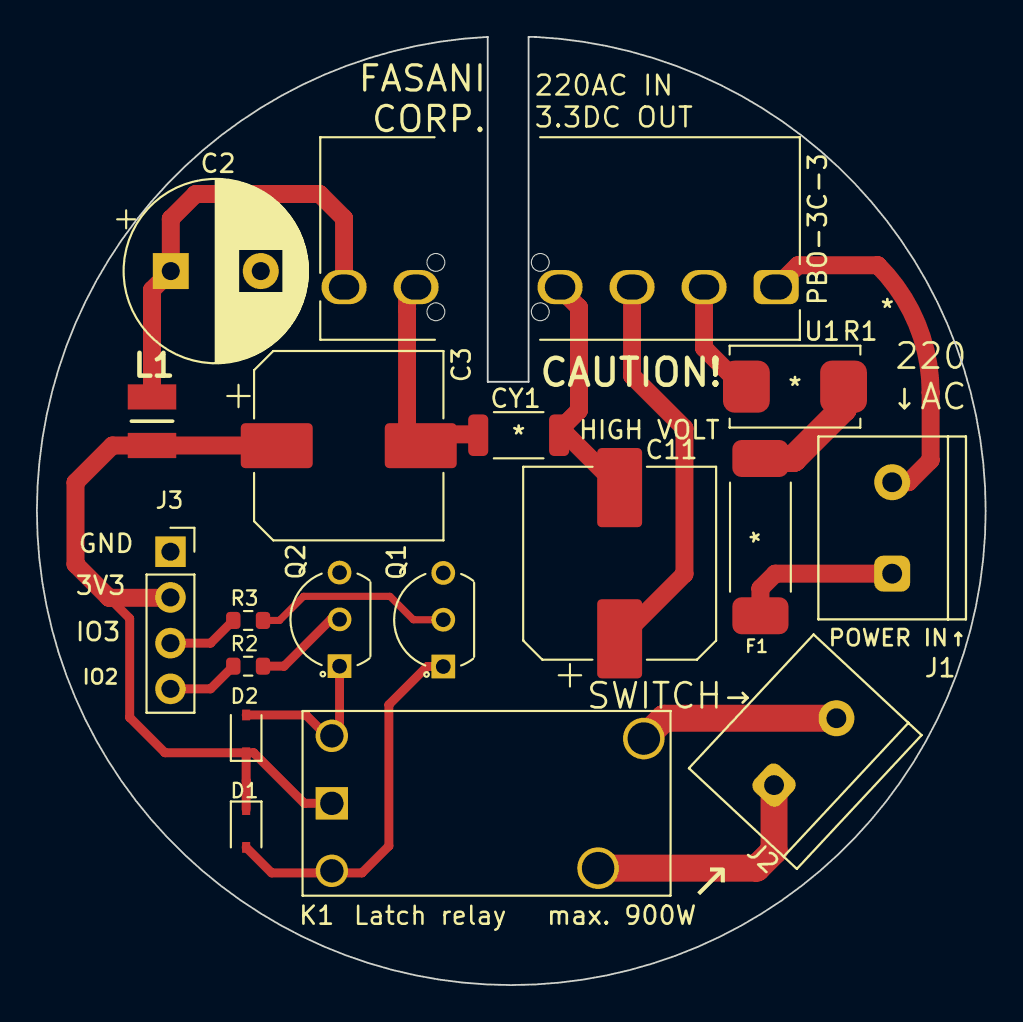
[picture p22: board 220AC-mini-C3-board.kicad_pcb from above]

Board: 2 copper layers, 52.7 x 52.7 mm, 18 parts (0 on the bottom side), 17 nets.

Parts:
C2: 470uF; CP_Radial_D10.0mm_P5.00mm
C3: C 150uF; CP_Elec_10x10
C11: 12uF; CP_Elec_10x14.3
CY1: 1nF; CC1808KKX7RCBB102
D1, D2: 1N4148; D_SOD-323
F1: Fuse; 0443001.DR
J1: AC MAINS POWER; Conn_C8269
J2: ON/OFF switch; Conn_C8269
J3: Conn_01x04; PinSocket_1x04_P2.54mm_Vertical
K1: HF163-F; FH44L-1AT-L2-DC3V
L1: L; IND_BRL3225T4R7M
Q1, Q2: Q_NPN_CBE; BC547B
R1: R; SMW212RJT
R2, R3: 430Ω; R_0603_1608Metric
U1: PBO-3C-3

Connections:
+3V3: C3.1, D1.1 (K), D2.1 (K), J3.2, K1.2, L1.2
/AC (N): J1.2, U1.1 (ACL)
/IO_2: J3.4, R2.2
/IO_3: J3.3, R3.2
AC: F1.1, J1.1
GND: C2.2, C3.2, CY1.1, J3.1, Q1.3 (E), Q2.3 (E), U1.5 (-VO)
unnamed: C11.1, U1.3 (+VCAP)
unnamed: C11.2, CY1.2, U1.4 (-VCAP)
unnamed: C2.1, L1.1, U1.6 (+VO)
unnamed: D1.2 (A), K1.1, Q1.1 (C)
unnamed: D2.2 (A), K1.3, Q2.1 (C)
unnamed: F1.2, R1.1
unnamed: J2.1, K1.5
unnamed: J2.2, K1.4
unnamed: Q1.2 (B), R3.1
unnamed: Q2.2 (B), R2.1
unnamed: R1.2, U1.2 (ACN)

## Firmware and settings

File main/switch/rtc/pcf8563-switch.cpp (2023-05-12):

/**
 * This is a demo to be used with Good Display 2.7 touch epaper 
 */ 
#include <stdio.h>
#include <inttypes.h>
#include "freertos/FreeRTOS.h"
#include "freertos/task.h"
#include "freertos/queue.h"
#include "driver/gpio.h"
// I2C RTC
#include "pcf8563.h"
#define CONFIG_NTP_SERVER "pool.ntp.org"
// I2C Touch
#include "FT6X36.h"
// Non-Volatile Storage (NVS)
#include "esp_system.h"
#include "nvs_flash.h"
#include "nvs.h"
// Time & WiFi
#include <time.h>
#include <sys/time.h>
#include "esp_wifi.h"
#include "protocol_examples_common.h"
#include "esp_sntp.h"
// Translations: select only one
#include "english.h"
//#include "gdew027w3.h"
//#include "goodisplay/gdey0154d67.h" // Tiny switch test
#include "goodisplay/gdey027T91.h"

// INTGPIO is touch interrupt, goes low when it detects a touch, which coordinates are read by I2C
// #define DEBUG_COUNT_TOUCH   // Only debugging
FT6X36 ts(CONFIG_TOUCH_INT);
EpdSpi io;
Gdey027T91 display(io);

// 1||3 = Landscape  0||2 = Portrait mode. Using 0 usually the bottom is at the side of FPC connector
uint8_t display_rotation = 1;
// Mono mode = true for faster monochrome update. 4 grays is nice but slower
bool display_mono_mode = true;


/** DEVICE CONSUMTION CONFIG 
    Please edit this two values to make the switch aware of how much consumes the lamp you are controlling */
#define DEVICE_CONSUMPTION_WATTS 100
double  DEVICE_KW_HOUR_COST    = 0.4;  // € or $ in device appears only $ since there is an issue printing Euro sign


// Relay Latch (high) / OFF
#define GPIO_RELAY_ON 2
#define GPIO_RELAY_OFF 3
// GPIO_NUM_2 in C3 | GPIO_NUM_1 in watch mini PCB 
#define RTC_INT GPIO_NUM_2
// Pulse to move the switch in millis
const uint16_t signal_ms = 50;

// Each time the counter hits this amount, store seconds counter in NVS and commit
// Make this please multiple of 60 or you can get an inexact count (Will also show Red alert in Serial)
const uint16_t nvs_save_each_secs = 240;

xQueueHandle on_min_counter_queue;

// FONT used for title / message body - Only after display library
//Converting fonts with ümlauts: ./fontconvert *.ttf 18 32 252

// Fonts are already included in components Fonts directory (Check it's CMakeFiles)
#include <Ubuntu_L7pt8b.h>
#include <Ubuntu_M16pt8b.h>
#include <Ubuntu_M36pt7b.h>

static const char *TAG = "PCF switch";
struct tm rtcinfo;
nvs_handle_t storage_handle;
// Every minute the current_month count is updated
int32_t min_l = 0;
int32_t min_c = 0;

// Switch always starts OFF when Firmware starts
bool switch_state = false; // starts false = OFF

int switch_on_sec_count = 0;
int switch_all_sec_count = 0;

// I2C descriptor
i2c_dev_t dev;

extern "C"
{
   void app_main();
}
void delay(uint32_t millis) { vTaskDelay(millis / portTICK_PERIOD_MS); }

void time_sync_notification_cb(struct timeval *tv)
{
    ESP_LOGI(TAG, "Notification of a time synchronization event");
}

static void initialize_sntp(void)
{
    ESP_LOGI(TAG, "Initializing SNTP");
    sntp_setoperatingmode(SNTP_OPMODE_POLL);
    ESP_LOGI(TAG, "Your NTP Server is %s", CONFIG_NTP_SERVER);
    sntp_setservername(0, CONFIG_NTP_SERVER);
    sntp_set_time_sync_notification_cb(time_sync_notification_cb);
    sntp_init();
}

static bool obtain_time(void)
{
    ESP_ERROR_CHECK( esp_netif_init() );
    ESP_ERROR_CHECK( esp_event_loop_create_default() );

    /* This helper function configures Wi-Fi or Ethernet, as selected in menuconfig.
     * Read "Establishing Wi-Fi or Ethernet Connection" section in
     * examples/protocols/README.md for more information about this function.
     */
    ESP_ERROR_CHECK(example_connect());

    initialize_sntp();

    // wait for time to be set
    int retry = 0;
    const int retry_count = 10;
    while (sntp_get_sync_status() == SNTP_SYNC_STATUS_RESET && ++retry < retry_count) {
        ESP_LOGI(TAG, "Waiting for system time to be set... (%d/%d)", retry, retry_count);
        vTaskDelay(2000 / portTICK_PERIOD_MS);
    }

    ESP_ERROR_CHECK( example_disconnect() );
    if (retry == retry_count) return false;
    return true;
}

static void IRAM_ATTR gpio_interrupt_handler(void *args)
{
    int pinNumber = (int)args;
    xQueueSendFromISR(on_min_counter_queue, &pinNumber, NULL);
}

void on_Task(void *params)
{
    int pinNumber; // IO with interrupt
  
    while (true)
    {
        if (xQueueReceive(on_min_counter_queue, &pinNumber, portMAX_DELAY))
        {
            switch_all_sec_count++;
            if (switch_all_sec_count % nvs_save_each_secs == 0) {
                // This should be done in a much more efficient way
                if (pcf8563_get_time(&dev, &rtcinfo) == ESP_OK) {
                    // Each day 1 at 00:00 HRs reset secs counter and save last month in min_l
                    ESP_LOGI("PCF8563", "Attempt RST counter|mday:%d hr:%d min:%d", rtcinfo.tm_mday,rtcinfo.tm_hour, rtcinfo.tm_min);
                    uint8_t save_each_mins = nvs_save_each_secs/60;
                    if (rtcinfo.tm_mday == 1 && rtcinfo.tm_hour == 0 && rtcinfo.tm_min <= save_each_mins*2 && min_c > save_each_mins) {
                        printf("RESET Counter and save last month totals\n\n");
                        nvs_set_i32(storage_handle, "min_l", min_c);
                        min_l = min_c;
                        min_c = -1;
                        switch_on_sec_count = 0;
                        switch_all_sec_count = 0;
                    }
                } else {
                    ESP_LOGE("on_Task", "DS3231 could not get_time");
                }
          }
          // Count only when switch is ON
            if (switch_state) {
                switch_on_sec_count++;
                if (switch_on_sec_count % nvs_save_each_secs == 0) {
                        min_c += nvs_save_each_secs /60;
                        nvs_set_i32(storage_handle, "min_c", min_c);
                        esp_err_t err = nvs_commit(storage_handle);
                        printf((err != ESP_OK) ? "NVS persist failed!\n" : "NVS commit\n");
                    }
          }
          // Clear timer flags
          pcf8563_get_flags(&dev);

          printf("ON:%d sec,%d min|pow:%s\n",
          switch_on_sec_count, (int)min_c, (switch_state)?(char*)"ON":(char*)"OFF");
        }
    }
}

// Some GFX constants
uint16_t blockHeight = display.height()/4;
uint16_t lineSpacing = 18;
uint16_t circleColor = EPD_BLACK;
uint16_t circleRadio = 10;
uint16_t selectTextColor  = EPD_WHITE;
uint16_t selectBackground = EPD_BLACK;

void draw_centered_text(const GFXfont *font, int16_t x, int16_t y, uint16_t w, uint16_t h, const char* format, ...) {
    // Handle printf arguments
    va_list args;
    va_start(args, format);
    char max_buffer[1024];
    int size = vsnprintf(max_buffer, sizeof max_buffer, format, args);
    va_end(args);
    string text = "";
    if (size < sizeof(max_buffer)) {
      text = string(max_buffer);
      
    } else {
      ESP_LOGE("draw_centered_text", "max_buffer out of range. Increase max_buffer!");
    }
    // Draw external boundary where text needs to be centered in the middle
    //printf("drawRect x:%d y:%d w:%d h:%d\n\n", x, y, w, h);
    display.fillRect(x, y, w, h, EPD_WHITE);
    display.setFont(font);
    int16_t text_x = 0;
    int16_t text_y = 0;
    uint16_t text_w = 0;
    uint16_t text_h = 0;

    display.getTextBounds(text.c_str(), x, y, &text_x, &text_y, &text_w, &text_h);

    if (text_w > w) {
        ESP_LOGI("draw_centered_text", "W: Text width out of bounds");
    }
    if (text_h > h) {
        ESP_LOGI("draw_centered_text", "W: Text height out of bounds");
    }
    // Calculate the middle position
    text_x += (w-text_w)/2;
    uint ty = (h/2)+y+(text_h/2);
    display.setCursor(text_x, ty);
    display.print(text);
}

void switchState(bool state) {
  if (state) {
    gpio_set_level((gpio_num_t)GPIO_RELAY_ON, 1); // OFF
    delay(signal_ms);
    gpio_set_level((gpio_num_t)GPIO_RELAY_ON, 0); // OFF release
  } else {
    gpio_set_level((gpio_num_t)GPIO_RELAY_OFF, 1); // OFF
    delay(signal_ms);
    gpio_set_level((gpio_num_t)GPIO_RELAY_OFF, 0); // OFF release
  }
}

void setClock()
{
    // obtain time over NTP
    ESP_LOGI(pcTaskGetName(0), "Connecting to WiFi and getting time over NTP.");
    if(!obtain_time()) {
        ESP_LOGE(pcTaskGetName(0), "Fail to getting time over NTP.");
        while (1) { vTaskDelay(1); }
    }

    // update 'now' variable with current time
    time_t now;
    struct tm timeinfo;
    char strftime_buf[64];
    time(&now);
    now = now + (CONFIG_TIMEZONE*60*60);
    localtime_r(&now, &timeinfo);
    strftime(strftime_buf, sizeof(strftime_buf), "%c", &timeinfo);
    ESP_LOGI(pcTaskGetName(0), "The current date/time is: %s", strftime_buf);

    // RTC is already initialized at this point

    ESP_LOGD(pcTaskGetName(0), "timeinfo.tm_sec=%d",timeinfo.tm_sec);
    ESP_LOGD(pcTaskGetName(0), "timeinfo.tm_min=%d",timeinfo.tm_min);
    ESP_LOGD(pcTaskGetName(0), "timeinfo.tm_hour=%d",timeinfo.tm_hour);
    ESP_LOGD(pcTaskGetName(0), "timeinfo.tm_wday=%d",timeinfo.tm_wday);
    ESP_LOGD(pcTaskGetName(0), "timeinfo.tm_mday=%d",timeinfo.tm_mday);
    ESP_LOGD(pcTaskGetName(0), "timeinfo.tm_mon=%d",timeinfo.tm_mon);
    ESP_LOGD(pcTaskGetName(0), "timeinfo.tm_year=%d",timeinfo.tm_year);

    struct tm time = {
        .tm_sec  = timeinfo.tm_sec,
        .tm_min  = timeinfo.tm_min,
        .tm_hour = timeinfo.tm_hour,
        .tm_mday = timeinfo.tm_mday,
        .tm_mon  = timeinfo.tm_mon,  // 0-based
        .tm_year = timeinfo.tm_year + 1900,
        .tm_wday = timeinfo.tm_wday
    };

    if (pcf8563_set_time(&dev, &time) != ESP_OK) {
        ESP_LOGE(pcTaskGetName(0), "pcf8563 Could not set time.");
        while (1) { vTaskDelay(1); }
    }
    ESP_LOGI(pcTaskGetName(0), "Set initial date time done");
}

void getClock() {
  display.fillScreen(EPD_WHITE); // Clean display
  // I2CDEV: Could not read from device in the 2x time. TODO: Find why
  // Get RTC date and time
  if (pcf8563_get_time(&dev, &rtcinfo) != ESP_OK) {
      ESP_LOGE(TAG, "getClock: Could not get time. Error coming second time on read attempt. Not fixed yet");
      return;
  }

  ESP_LOGI("CLOCK", "\n%s\n%02d:%02d", weekday_t[rtcinfo.tm_wday], rtcinfo.tm_hour, rtcinfo.tm_min);

  // Starting coordinates:
  uint16_t y_start = display.height()-20;
  uint16_t x_cursor = 1;
  // For portrait mode update this coordinates
  if (display_rotation == 0 || display_rotation == 2) {
    y_start = 5;
  }
  
  // Calculate consumption with this inputs: DEVICE_KW_HOUR_COST nvs_watts switch_on_sec_count
  double total_kw = (double)DEVICE_CONSUMPTION_WATTS / (double)1000;
  double switch_hrs = (double)switch_on_sec_count/(double)3600;
  double total_kw_current_mon = total_kw * switch_hrs;
  double total_kw_cost = total_kw_current_mon * DEVICE_KW_HOUR_COST;

  // Temp excluded:  %.1f°C
  //draw_centered_text(const GFXfont *font, int16_t x, int16_t y, uint16_t w, uint16_t h, const char* format, ...)
  draw_centered_text(&Ubuntu_L7pt8b,x_cursor,y_start,display.width(),12,"%.2f Kw %.2f $", total_kw_current_mon, total_kw_cost);
  
  // Convert seconds into HHH:MM:SS
  int hr,m,s;
  hr = (switch_on_sec_count/3600);
  m = (switch_on_sec_count -(3600*hr))/60;
  s = (switch_on_sec_count -(3600*hr)-(m*60));

  x_cursor = display.width()/2+30;
  if (display_rotation == 0 || display_rotation == 2) {
    y_start = display.height()-20;
    x_cursor = 10;
  }

  draw_centered_text(&Ubuntu_L7pt8b,1,1,display.width(),18,"%03d:%02d:%02d ON", hr, m, s);
}

void drawUX(int tx, int ty) {
  getClock();
  if (tx != 0 && ty != 0) {
    draw_centered_text(&Ubuntu_L7pt8b, 1, 20, display.width(), 18, "x:%d y:%d", tx, ty);
  }
  uint16_t dw = display.width();
  uint16_t dh = display.height();
  uint8_t  sw = 20;
  uint8_t  sh = 50;
  uint8_t  keyw = 16;
  uint8_t  keyh = 16;
  display.fillRoundRect(dw/2-sw/2, dh/2-sh/2, sw, sh, 4, EPD_WHITE);
  display.drawRoundRect(dw/2-sw/2, dh/2-sh/2, sw, sh, 4, EPD_BLACK);

  // OFF position
  if (!switch_state) {
    display.fillRoundRect(dw/2-keyw/2, dh/2, keyw, keyh, 5, EPD_BLACK);
    gpio_set_level((gpio_num_t)GPIO_RELAY_OFF, 1); // OFF
    delay(signal_ms);
    gpio_set_level((gpio_num_t)GPIO_RELAY_OFF, 0); // OFF release
    printf("Draw OFF\n\n");
  } else {
    display.fillRoundRect(dw/2-keyw/2, dh/2-keyh, keyw, keyh, 5, EPD_BLACK);
    gpio_set_level((gpio_num_t)GPIO_RELAY_ON, 1); // ON
    delay(signal_ms);
    gpio_set_level((gpio_num_t)GPIO_RELAY_ON, 0); // ON release
    printf("Draw ON\n\n");
  }
  
  char * label = (switch_state) ? (char *)"ON" : (char *)"OFF";
  draw_centered_text(&Ubuntu_L7pt8b, dw/2-22, dh/2-sh, 40, 20, label);

  display.update();
  // It does not work correctly with partial update leaves last position gray
  //display.updateWindow(dw/2-40, dh/2-keyh-40, 100, 86);
}

uint16_t t_counter = 0;

void touchEvent(TPoint p, TEvent e)
{
  #if defined(DEBUG_COUNT_TOUCH) && DEBUG_COUNT_TOUCH==1
    ++t_counter;
    printf("e %x %d  ",e,t_counter); // Working
  #endif

  if (e != TEvent::Tap && e != TEvent::DragStart && e != TEvent::DragMove && e != TEvent::DragEnd)
    return;

  switch_state = !switch_state;
  
  drawUX(p.x,p.y);
}

// Generic function to read NVS values and leave feedback
void err_announcer(esp_err_t err, char * name, int value) {
    switch (err) {
        case ESP_OK:
            printf("OK %s=%d\n", name, value);
            break;
        case ESP_ERR_NVS_NOT_FOUND:
            printf("The %s is not initialized yet in NVS\n", name);
            break;
        default :
            ESP_LOGE(name, "Error (%s) reading!\n", esp_err_to_name(err));
    }
}

void app_main(void)
{
  printf("CalEPD version: %s\nLast reset reason:%d\n", CALEPD_VERSION, esp_reset_reason());

  // Initialize NVS
  esp_err_t err = nvs_flash_init();
  if (err == ESP_ERR_NVS_NO_FREE_PAGES || err == ESP_ERR_NVS_NEW_VERSION_FOUND) {
      // NVS partition was truncated and needs to be erased
      // Retry nvs_flash_init
      ESP_ERROR_CHECK(nvs_flash_erase());
      err = nvs_flash_init();
  } else {
    printf("NVS initialized\n");
  }
  ESP_ERROR_CHECK(err);

  err = nvs_open("storage", NVS_READWRITE, &storage_handle);
  if (err != ESP_OK) {
      ESP_LOGE(TAG, "Error (%s) opening NVS handle!\n", esp_err_to_name(err));
  } else {
    printf("NVS opened\n");
  }

  gpio_set_direction(RTC_INT, GPIO_MODE_INPUT);
  gpio_pullup_en(RTC_INT);
  // Setup interrupt for this IO that goes low on the interrupt
  gpio_set_intr_type(RTC_INT, GPIO_INTR_NEGEDGE);
  ESP_LOGI("RTC INT", "when IO %d is Low", (int)RTC_INT);

  //Initialize GPIOs direction & initial states
  gpio_set_direction((gpio_num_t)GPIO_RELAY_ON, GPIO_MODE_OUTPUT);
  gpio_set_direction((gpio_num_t)GPIO_RELAY_OFF, GPIO_MODE_OUTPUT);
  switchState(false); // OFF at the beginning
  
  // Read values from Non Volatile Storage
  err = nvs_get_i32(storage_handle, "min_c", &min_c); // Current month
  err_announcer(err, (char *)"min_c", min_c);
  err = nvs_get_i32(storage_handle, "min_l", &min_l); // Last month (still not shown in UX)
  err_announcer(err, (char *)"min_l", min_l);
  // Initialize ON count with NVS count
  switch_on_sec_count = min_c*60;
  // Initialize Epd class, set rotation, default Font and orientation
  display.init();
  /**
   * @brief Note: 4 gray uses a second buffer. 
   * Nice thing about disabling is that all what you write in gray will not be visible when you are in mono mode
   */
  display.setMonoMode(display_mono_mode); // 4 gray: false
  display.setRotation(display_rotation);
  display.setFont(&Ubuntu_L7pt8b);
  display.setTextColor(EPD_BLACK);
  printf("DISPLAY width() %d height() %d\n", display.width(), display.height());

// Initialize RTC
  if (pcf8563_init_desc(&dev, I2C_NUM_0, (gpio_num_t) CONFIG_SDA_GPIO, (gpio_num_t)CONFIG_SCL_GPIO) != ESP_OK) {
      ESP_LOGE(pcTaskGetName(0), "Could not init PCF8563 descriptor since touch already did that");
  }
  
  // If time is not set then resync with WiFi (Make sure to add your WLAN access point name and password in:
  // idf.py menuconfig -> Example Connection configuration
  
  if (pcf8563_get_time(&dev, &rtcinfo) != ESP_OK) {
     ESP_LOGE(TAG, "Could not get time, please check that the I2C wiring is correct and has pull-ups in place in SCL / SDA lines.");
     return;
  }
  printf("pcf8563 TIME: %02d:%02d %02d/%02d/%d\n\n", rtcinfo.tm_hour, rtcinfo.tm_min,
                                  rtcinfo.tm_mday, rtcinfo.tm_mon+1, rtcinfo.tm_year);
  
  #ifdef CONFIG_SET_CLOCK
     printf("Y:%d m:%d -> Calling NTP internet sync\n\n", rtcinfo.tm_year, rtcinfo.tm_mon);
     display.setCursor(10,10);
     display.print("RTC time & second alarm not set");
     display.setCursor(10,40);
     display.print("Connecting to do NTP time sync");
     display.update();
     setClock();
  #endif

  // Every second         1 sec= 1 HZ , divider (If it would be two then will tick 2x per second)
  pcf8563_set_timer(&dev, PCF8563_CLK_1HZ, 1);
  pcf8563_enable_timer(&dev);
  pcf8563_get_flags(&dev);
  printf("After RTC int state: %d (Should be 1 at start, if not check pullup in %d GPIO)\n\n", RTC_INT, gpio_get_level(RTC_INT));

  // PCF Minute alarm: Still need to find out how to correctly set it and extend my class
  gpio_install_isr_service(0); // Is already used by touch!
  // Reason is that RTC is in control of this Interrupt when PCF starts
  gpio_isr_handler_add(RTC_INT, gpio_interrupt_handler, (void *)RTC_INT);
  on_min_counter_queue = xQueueCreate(10, sizeof(int));
  xTaskCreate(on_Task, "on-counter", 2048, NULL, 1, NULL);

  ts.begin(FT6X36_DEFAULT_THRESHOLD, display.width(), display.height());
  ts.setRotation(display.getRotation());
  ts.registerTouchHandler(touchEvent);
  
  drawUX(0,0);
  // Touch loop. If youu find a smarter way to do this please make a Merge request ( github.com/martinberlin/FT6X36-IDF )
  while (true) {
    ts.loop();
  }
}

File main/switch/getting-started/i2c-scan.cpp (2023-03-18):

// Just a quick I2C Address scan.

// Define yours here or copy the ones you use for touch
// By default for S3 PCB is SDA: 7  SCL: 15
#define SDA_GPIO CONFIG_TOUCH_SDA
#define SCL_GPIO CONFIG_TOUCH_SDL

#define I2C_MASTER_FREQ_HZ 100000                     /*!< I2C master clock frequency */
#define I2C_SCLK_SRC_FLAG_FOR_NOMAL       (0)         /*!< Any one clock source that is available for the specified frequency may be choosen*/

#include <stdio.h>
#include "esp_log.h"
#include "freertos/FreeRTOS.h"
#include "freertos/task.h"
#include "driver/i2c.h"
#include "driver/gpio.h"

#if ESP_IDF_VERSION >= ESP_IDF_VERSION_VAL(5, 0, 0)
  #define portTICK_RATE_MS portTICK_PERIOD_MS
#endif
// Enable on HIGH 5V boost converter
#define GPIO_ENABLE_5V GPIO_NUM_38

static const char *TAG = "i2c test";

extern "C"
{
    void app_main();
}

// setup i2c master
static esp_err_t i2c_master_init()
{
    i2c_config_t conf;
    conf.mode = I2C_MODE_MASTER;
    conf.sda_io_num = SDA_GPIO;
    conf.scl_io_num = SCL_GPIO;
    conf.sda_pullup_en = GPIO_PULLUP_ENABLE;
    conf.scl_pullup_en = GPIO_PULLUP_ENABLE;
    conf.master.clk_speed = I2C_MASTER_FREQ_HZ;
    conf.clk_flags = I2C_SCLK_SRC_FLAG_FOR_NOMAL;

    i2c_param_config(I2C_NUM_0, &conf);
    return i2c_driver_install(I2C_NUM_0, conf.mode, 0, 0, 0);
}

void app_main()
{
    char * device = (char *)"unknown";
    ESP_LOGI(TAG, "SCL_GPIO = %d", SCL_GPIO);
    ESP_LOGI(TAG, "SDA_GPIO = %d", SDA_GPIO);
    
    // i2c init & scan
    if (i2c_master_init() != ESP_OK)
        ESP_LOGE(TAG, "i2c init failed\n");

    vTaskDelay(150 / portTICK_PERIOD_MS);
     printf("i2c scan: \n");
     for (uint8_t i = 1; i < 127; i++)
     {
        int ret;
        i2c_cmd_handle_t cmd = i2c_cmd_link_create();
        i2c_master_start(cmd);
        i2c_master_write_byte(cmd, (i << 1) | I2C_MASTER_WRITE, 1);
        i2c_master_stop(cmd);
        ret = i2c_master_cmd_begin(I2C_NUM_0, cmd, 100 / portTICK_RATE_MS);
        i2c_cmd_link_delete(cmd);
    
        if (ret == ESP_OK)
        {
            switch (i)
            {
            case 0x38:
                device = (char *)"FT6X36 Touch";
                break;
            case 0x51:
                device = (char *)"PCF8563 RTC";
                break;
            case 0x68:
                device = (char *)"DS3231 RTC";
                break;
            default:
                device = (char *)"unknown";
                break;
            }
            printf("Found device at: 0x%2x %s\n", i, device);
        }
    }
}

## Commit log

2023-02-18 Initial commit with basic example that builds
    [case-switch-epaper.stl]
2023-02-18 Add Hardware section
    [0443Series_LTF.step, 1729128-screw-terminal.stp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]
2023-02-19 Add sdk-config-board example
2023-02-19 220AC 3.3DC adapter redesigned 1.1
    [220AC-mini-C3-board-square-54mm.kicad_pcb, 220AC-mini-C3-board.kicad_sch, BRL3225T4R7M-L1.step]
2023-02-19 HW Add 3D models & update footprints
2023-02-19 Update kicad PCB
    [220AC-mini-C3-board.kicad_pcb]
2023-02-19 Make revision folders also for production
    [220AC-mini-C3-board-BOM.csv, 220AC-mini-C3-board-BOM.xlsx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]
2023-02-20 S3 pro release 1.0
    [0443Series_LTF.step, AP22802AW5-7.step, CP2102N-A02-GQFN28R.step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]
2023-02-20 Clear DRC errors
    [C3-27-BOM.xlsx, S3-27-epaper-touch.kicad_pcb, S3-27-epaper-touch.kicad_sch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]
2023-02-20 S3: Do not use MOSI in JTAG data pins
    [S3-27-epaper-touch.kicad_pcb, S3-27-epaper-touch.kicad_sch]
2023-02-21 Add also I2Cscanner example
2023-02-22 Update R15 thx. @Uspizig
    [S3-27-epaper-touch.kicad_pcb, S3-27-epaper-touch.kicad_sch]
2023-02-22 Error detected by @ispizig. Thanks!
    [S3-27-epaper-touch.kicad_pcb, S3-27-epaper-touch.kicad_sch]
2023-02-23 #2 Store every minute passed in NVS. Restart from there in case of reset
    [rtc-switch.cpp]
2023-02-24 Move C3 version but w/PCF8563 RTC
    [0443Series_LTF.step, AP22802AW5-7.step, C3-27-BOM.xlsx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]
2023-02-24 Update C3 schematic
2023-02-24 Update C15 put it closer to LDO
    [C3-27-epaper-touch-B_Cu.gbl, C3-27-epaper-touch-B_Mask.gbs, C3-27-epaper-touch-B_Paste.gbp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]
2023-02-25 C3 Rev 1.1 sent to fabrication
    [C3-27-BOM.xlsx, C3-27-epaper-touch.csv, C3-27-epaper-touch.kicad_pcb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]
2023-02-25 C3 Rev 1.2 start: Simplify routing
    [C3-27-epaper-touch.kicad_pcb]
2023-02-25 Mark properly D+ & D- lines
    [C3-27-epaper-touch.kicad_pcb, C3-27-epaper-touch.kicad_sch]
2023-02-26 Update 1.1 R14 & R15 VUSB sense CP2102
    [C3-27-epaper-touch.kicad_pcb, C3-27-epaper-touch.kicad_sch, C3-BOM.xlsx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]
2023-02-26 C3 1.1 remove C13 does not seem to be necessary (near CP2102)
    [C3-27-epaper-touch.kicad_pcb, C3-27-epaper-touch.kicad_sch, C3-BOM.xlsx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]
2023-02-26 Revert "C3 1.1 remove C13 does not seem to be necessary (near CP2102)"
    This reverts commit e9bbdf2bfd8dbd0aba68dd1d7c9680fb7645ba6f.
    [C3-27-epaper-touch.kicad_pcb, C3-27-epaper-touch.kicad_sch, C3-BOM.xlsx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]
2023-02-26 C3 1.1 replace C13 to be 4.7uF
    [C3-27-epaper-touch.kicad_pcb, C3-27-epaper-touch.kicad_sch, C3-BOM.xlsx]
2023-02-26 C3 1.1 update Y1 crystal
    [XTAL_FC-135_EPS.step]
2023-02-27 cambios CAF
    [220AC-mini-C3-board-1.0.kicad_pcb, 220AC-mini-C3-board.kicad_sch]
2023-02-27 Make CAF refactoring pass schematics
    [220AC-mini-C3-board-1.0.kicad_pcb, 220AC-mini-C3-board.kicad_pcb]
2023-02-27 Update 3D and assign to latch relay
    [220AC-mini-C3-board.kicad_pcb]
2023-02-27 Update silkscreen
    [220AC-mini-C3-board.kicad_pcb]
2023-02-27 Update schematics
    [220AC-mini-C3-board.kicad_sch]
2023-02-27 C3 schematics keep up to date
2023-02-27 Remove innecesary GND since there is ground pane
    [220AC-mini-C3-board.kicad_pcb]
2023-03-01 H 220AC adapter silk
    [220AC-mini-C3-board.kicad_pcb]
2023-03-01 #8 Add basic calculation to rtc/ds3231-switch.cpp
2023-03-02 Exclude temperature (is not precise)
2023-03-04 S3 update to review: No more C 220uF RTC backup use CR1220
    [S3-27-epaper-touch.kicad_pcb, S3-27-epaper-touch.kicad_sch]
2023-03-07 Update S3 heading to 1.1 release
    [S3-27-epaper-touch.kicad_pcb, S3-27-epaper-touch.kicad_sch]
2023-03-08 #8 PCF switch C3 version. Pending issues
    [pcf8563-switch.cpp]
2023-03-09 #8 PCF8563 switch is working and counting consumption by minute
2023-03-15 C3 Rev 1.1 tests
    [C3-27-epaper-touch.kicad_pcb]
2023-03-15 1.2 is ready, this time MCU can be soldered already
    [C3-27-epaper-touch.kicad_pcb, C3-27-epaper-touch.kicad_sch]
2023-03-17 C3 PCB add R16 current limiting for RTC backup CAPs
    [C3-27-epaper-touch.kicad_pcb, C3-27-epaper-touch.kicad_sch]
2023-03-18 Update schematics. Introduce Rev log
    [C3-27-epaper-touch.kicad_sch]
2023-03-18 Switch to updated PCF8563 component
2023-03-20 Correct edge-cuts for right FPC bending
    [C3-27-epaper-touch.kicad_pcb]
2023-03-22 Add 3D case file (Wall switch: 60 mm separated 3mm hole)
    [case-switch-epaper.stl]
2023-03-22 Add 3D full sources including blend (er) file
    [case-switch-epaper.blend, case-switch-epaper.stl]
2023-04-16 C3 PCB update RES label
    [220AC-mini-C3-board-B_Cu.gbl, 220AC-mini-C3-board-B_Mask.gbs, 220AC-mini-C3-board-B_Paste.gbp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]
2023-04-17 Optimize deepsleep for C3 version
    [C3-27-epaper-touch.kicad_pcb, C3-27-epaper-touch.kicad_sch]
2023-04-17 Switch LDO to RT9013-33GB Ref https://github.com/martinberlin/H-spi-adapters/issues/9
    [C3-27-epaper-touch.kicad_pcb, C3-27-epaper-touch.kicad_sch, RT9013-33GB.step]
2023-04-17 Update C3 schematics with new LDO

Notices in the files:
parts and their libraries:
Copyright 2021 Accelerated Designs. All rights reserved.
